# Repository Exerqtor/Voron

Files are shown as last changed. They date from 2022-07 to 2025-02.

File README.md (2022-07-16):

# Voron stuff

This is where i will upload my Voron related stuff, enjoy!

Check out the [`Mods`](./Mods) [`Firmware`](./Firmware) and [`SlicerConfigs`](./SlicerConfigs) folders for my mods that are still 
considered (by me) to be relevant. All abandoned mods can be found in the [`AbandonedMods`](./AbandonedMods) folder.

Voron Logo

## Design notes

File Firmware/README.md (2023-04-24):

# Firmware

My firmware configurations and Macros for Voron 3D printers, separated by firmware type.

## Table structure

Update the following table with the information about your mod:
- Your name
- A link to your sub-folder
- A short description of your firmware config
- The printer compatibility. Use `:heavy_check_mark:` for :heavy_check_mark:,`:x:` for :x: and `:grey_question:` for :grey_question:

like so:
`
| Creator | [Config Title](link) | Description | :x: | :x: | :x: | :x: |`

---
## RepRapFirmware

| Creator | Config title | Description | V0 | V1.8 | V2.4 | VSW | VT |
| --- | --- | --- | --- | --- | --- | --- | --- |
| Exerqtor | [Duet 3 Config](./reprapfirmware/) | My RRF 3.5 config | :x: | :x: | :x: | :x: | :heavy_check_mark:
|| [RRF Macros](./rrf-macros/) | RepRapFirmware macros for Voron printers| - | - | - | - | - | |

---

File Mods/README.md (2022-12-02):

# Mods

Printer mods for Voron 3D printers
Remember to update this README when uploading new mod!

## Legacy printers

Mods for legacy printers can be found [here](../legacy_printers/printer_mods).
If one of your mods applies to a current generation Voron printer, contact the admins in
Discord to have your mod moved to this folder.

## Table structure

Update the following table with the information about your mod:
- Your name
- A link to your sub-folder
- A short description of your mod
- The printer compatibility. Use `:heavy_check_mark:` for :heavy_check_mark:,`:x:` for :x: and `:grey_question:` for :grey_question:

like so:
`
| Creator | [Mod title](link) | Description | :x: | :x: | :x: | :x: | :x: |`

---

| Creator | Mod title | Description | V0 | V1.8 | V2.4 | VSW | VT |
| --- | --- | --- | --- | --- | --- | --- | --- |
|Exerqtor|[Revo nozzle storage skirt](./revo_nozzle_storage_skirt)| Revo nozzle storage that can hold 7 nozzles, for the side skirt(s). |:x:|:x:|:x:|:x:|:heavy_check_mark:|
||[StealthBurner / CW2 style LGX Lite mount](./stealthburner_cw2_style_lgx_lite_mount)| A lightweight Bondtech LGX lite mount for StealthBurner / CW2 carriage with detection filament sensor .|:x:|:grey_question:|:heavy_check_mark:|:grey_question:|:heavy_check_mark:|
||[Pepe pack v2](./pepe_pack_v2)| A rear mounted alternative to the Nevermore filter .|:x:|:grey_question:|:heavy_check_mark:|:x:|:heavy_check_mark:|
||[Quick release exhaust mount](./quick_release_exhaust_mount)| Quick release system ("Annex-style") for the exhaust housing on the rear panel.|:x:|:heavy_check_mark:|:heavy_check_mark:|:grey_question:|:heavy_check_mark:|
||[Trident PTFE Support-v2](./trident_ptfe_support-v2)| PTFE support arm that mounts on the top rear extrusion on a Trident, WITH bearing.|:x:|:x:|:x:|:x:|:heavy_check_mark:|
||[MGN12H rear Z carrier for Trident](./mgn12h_rear_z)| Rear Z carrier that allowes for the use of a MGN12H rail instead of MGN9H.|:x:|:x:|:x:|:x:|:heavy_check_mark:|
||[Trident PTFE Guides](./trident_ptfe_guides)| A guide for the PTFE tube into the extruder .|:x:|:grey_question:|:x:|:x:|:heavy_check_mark:|
||[VT Lowered Z Motor Mounts](./vt_lowered_Z_motor_mounts)| Z motor mounts that makes you use T8 leadscrews and couplers on a Trident.|:x:|:grey_question:|:x:|:x:|:heavy_check_mark:|
||[fume pack](./fume_pack)| A rear mounted alternative to the Nevermore filter, the successor of pepe pack v2 .|:x:|:grey_question:|:heavy_check_mark:|:x:|:heavy_check_mark:|

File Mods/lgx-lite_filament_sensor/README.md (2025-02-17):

# Filament runout sensor for Bondtech LGX lite (v1 & v2)

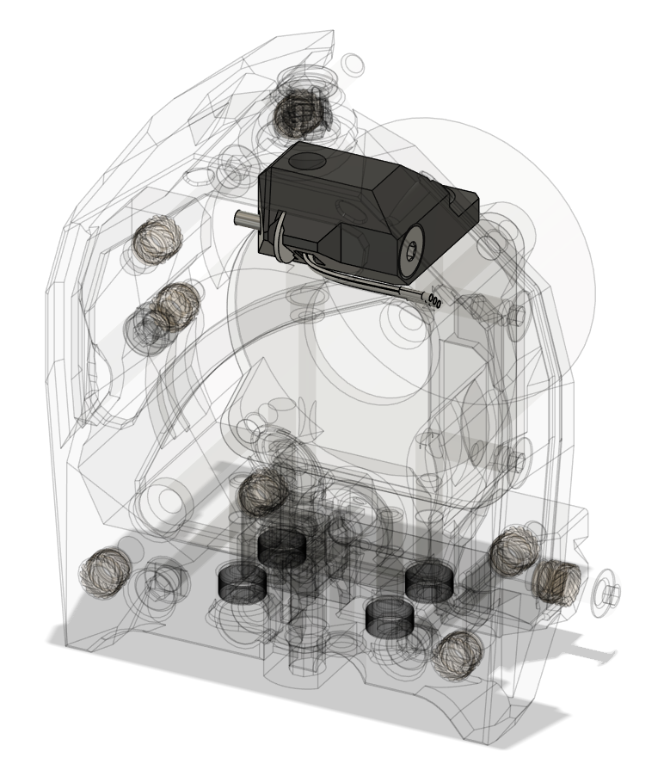
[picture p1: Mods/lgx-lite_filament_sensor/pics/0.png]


## CHANGELOG
- 17.02.2025: Initial release.

###### Printing:
- Default voron settings, correct orientation, no supports needed!

###### Bom:
- 2x 6mm FHCS - Needs to be stainless to avoid interference with the HALL sensor.
- 1x 3mm DIN washer - Needs to be steel to interact properly with the HALL sensor.
- 1x AH3364Q-P-B hall sensor - "Name brand" one from a reputable vendor  is adviced (but not a must).
- 1x 6x3mm magnet - Both N35 & N52 does the job, but N52 works the best.

###### Description:
- Initial design by Olof at Bondtech, and we've been collaborating to get it to it's current form. 
I've been testing different iderations of this for well over a year at this point and it's been working like a champ.
- The Sensor is meant to mount above the LGX Lite, inside Bondtechs mount (my MMU & Filametrix mounts are based of Bondtecs mounts so it naturally fits there too).

### !!ATTENTION!! This sensor does NOT work with the LGX Lite PRO, I have one in the works. But since i haven't got a LGX Lite PRO to test with this isn't getting prioritized. 

###### Assembly instructions:
- Prep the printed part by making sure any strings, blobs etc. is removed.
- Get the FHCS screw started about 2mm. into the side of the sensor body.
- Insert AH3364Q-P-B in it's slot.
  - If needed use a exacto knife to remove any print debris from the hall sensor slot so that it seats fully.
- Tighten down the screw while making sure the AH3364Q-P-B is still seated properly in the sensor housing.
- Insert the magnet and then the washer in their locations.
  - If the magnet feels a little loose when you put it in it's best to add a tiny drop of CA-glue or nail polish to secure it.
- Snip off a stump of 1.75mm filament and insert it into the hole in the side of the sensor body to retain the washer (and trim it to size, but leave enough that you can still use some pliers to remove it).
- Do a bench test with some filament and check that it can pass through the sensor without any issues.
- If you haven't done so allready you should now solder on some wires to the hall sensor before you bend the pins flush to the sensor body (like shown in the renders).
- Cut a piece of PTFE with the jig and insert it to the top/filament entrence of your LGX-lite.
- Mount the filament sensor with a the remaining 6mm FHCS (both 6mm and 8mm should work fine for this).

- I'm not gonna go into how you're supposed to solder, wire up & configure the HALL sensor for your machine but there’s more than enough information on the internet for you to figgure that out yourself ;)  

###### Pictures:
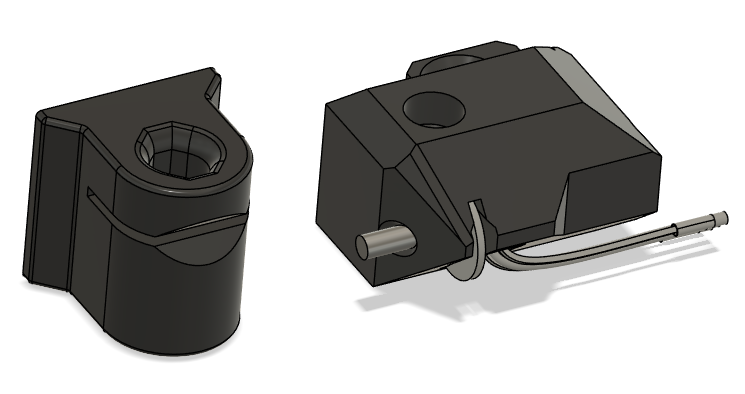
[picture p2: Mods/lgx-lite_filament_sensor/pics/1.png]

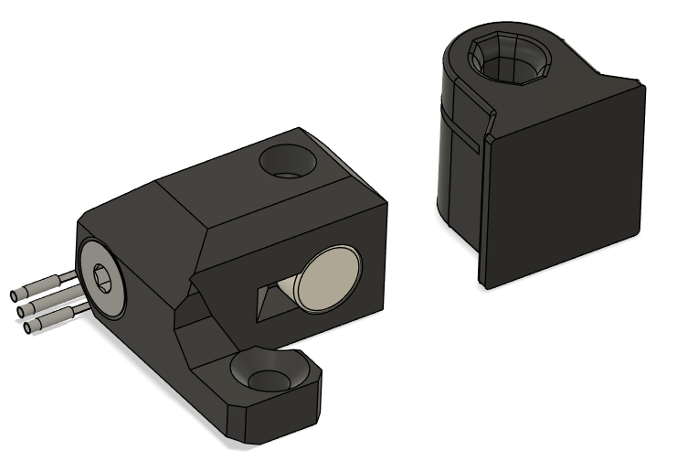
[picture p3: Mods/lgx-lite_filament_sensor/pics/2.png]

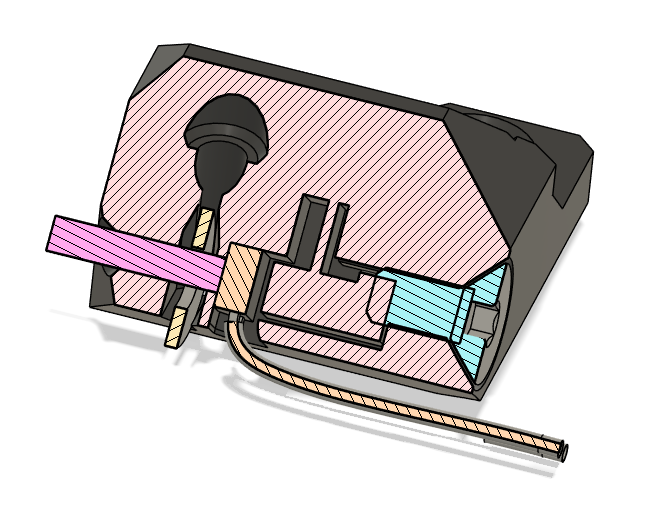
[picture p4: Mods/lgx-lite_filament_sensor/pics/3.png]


###### To-do List
- Nothing that i can think of.

##### Credits:
- Olof Ogland
- [ERCF project](https://github.com/Enraged-Rabbit-Community/ERCF_v2) for much of the sensor geometry.

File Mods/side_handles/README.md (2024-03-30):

# 2.4 & Trident side handles
### **CHANGELOG:**
- 30.03.2024: Initial release.

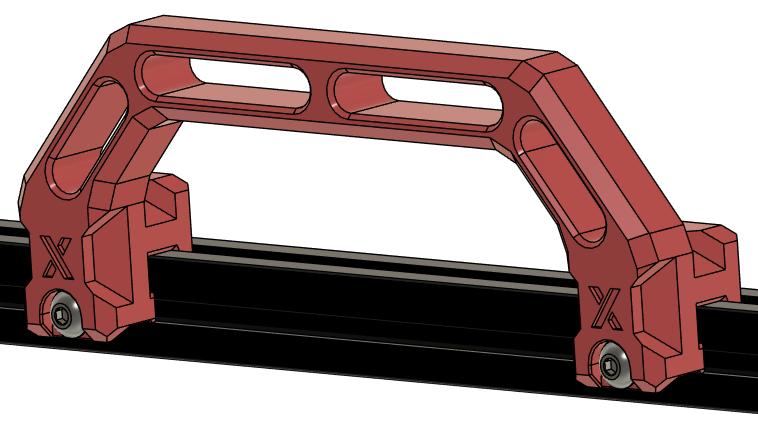
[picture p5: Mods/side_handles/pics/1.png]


### **Description:**
- I've been using the original “Sturdy Handles” before and they've done their job, but then I saw ["JSB's X-Handle"](https://www.printables.com/model/350891-voron-24-x-handle)  and I liked them, but they had some issues with the design. So I ended up doing the following:

- Removed the top mounting bolts in favour of a “lip” that goes into the 2020 extrusion like the original “sturdy handles”
- Added M3x20mm BHCS to mitigate a weak spot in the design where the handle meets the top part, where it "allways" cracked.
- Made modifier blocks to add denser/stronger types of infill around the problem area mentioned above.
- I've also made a second modifier block that makes it possible to add "fuzzy skin" to the handle without compromising the structual integrety while still giving that nice grippy texture (for those who wants it).

*I've also made a version of the handle that's stripped of the “X” since I just don't understand why it's there at all other than nonsensical “branding” (?) , to each their own i guess!*

### **Pictures:**
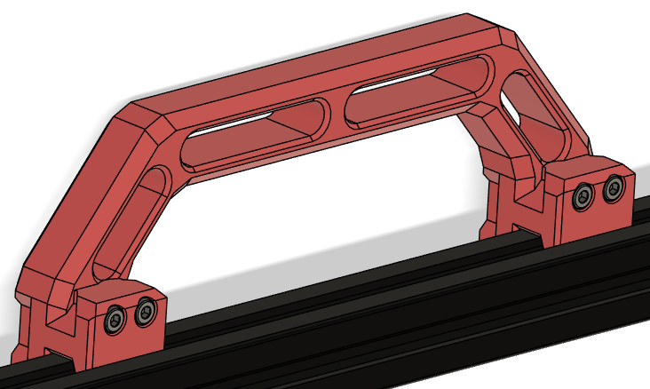
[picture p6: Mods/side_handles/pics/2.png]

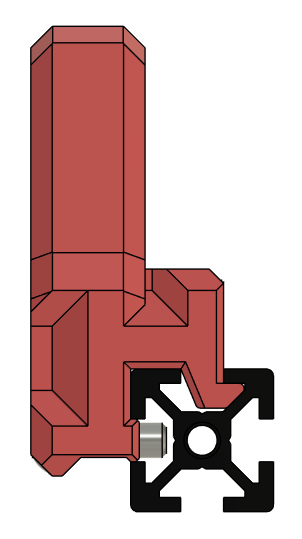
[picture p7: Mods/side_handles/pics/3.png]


### **Printing:**
- Default voron settings, correct orientation, no supprts needed!
- First load the handle itself to your slicer.
- Add "Infill.stl" as a modifier to the handle and adjust the infill properties of the modifier.(if you want to add other infill properties to the stress sones).
- Add "Fuzz.stl" as a modifier to the handle and enable fuzzy skin (contour) to the modifier (if you want to add texture to the handle).
If you've gone with both infill and fuzz you will end up with something like this:

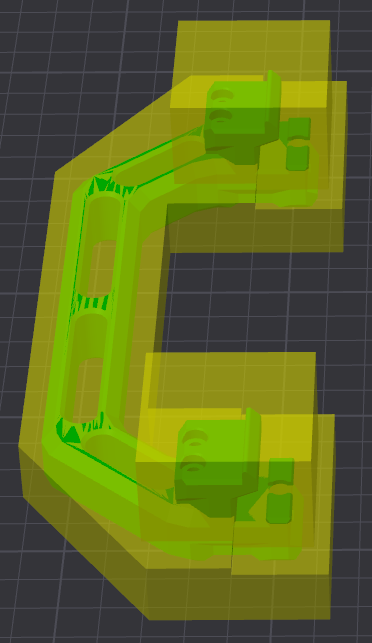
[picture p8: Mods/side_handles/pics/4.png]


This is the sliced view of mine when I use 40% Support Cubic infill on the handle, 40% 3D Honeycomb on the infill modifier & Countor fuzzy skin on the fuzz modifier:

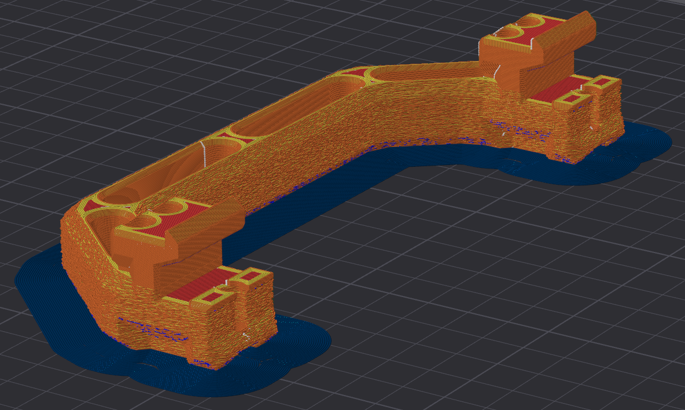
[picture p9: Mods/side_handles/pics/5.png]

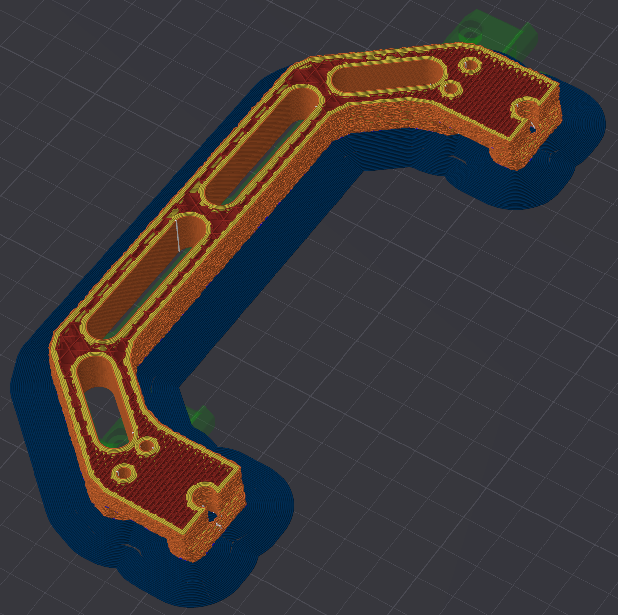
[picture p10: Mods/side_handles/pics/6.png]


### **BOM (per side):**
- 4x M3x20mm SHCS (for the handle reinforcement)
- 2x M5x16mm  BHCS
- 2x M5 Roll-in T-nuts

###### **To-do List:**
- Nothing that i can think of.

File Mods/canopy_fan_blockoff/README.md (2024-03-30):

# Canopy fan blockoff plates
### CHANGELOG
- 30.03.2024: Initial release.

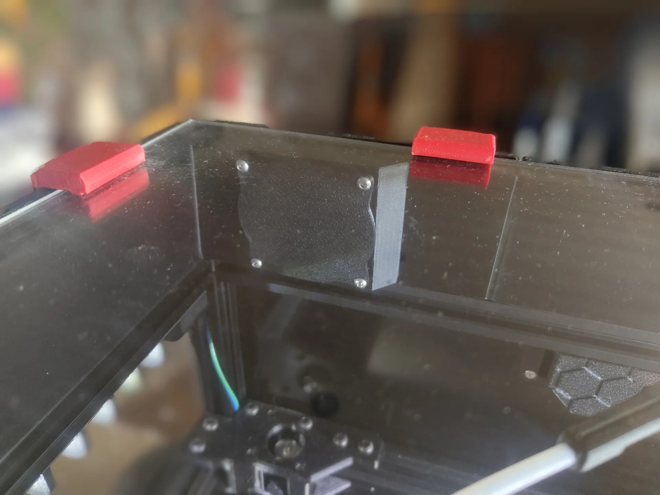
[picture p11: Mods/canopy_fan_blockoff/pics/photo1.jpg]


### Description:
- I didn't want to re-print the rear corners of  ["JSmith17's Canopy"](https://www.printables.com/model/568090-voron-24-canopy) in case I eventually add exhaust fans, so i made these blockoff plates instead.

### Pictures:
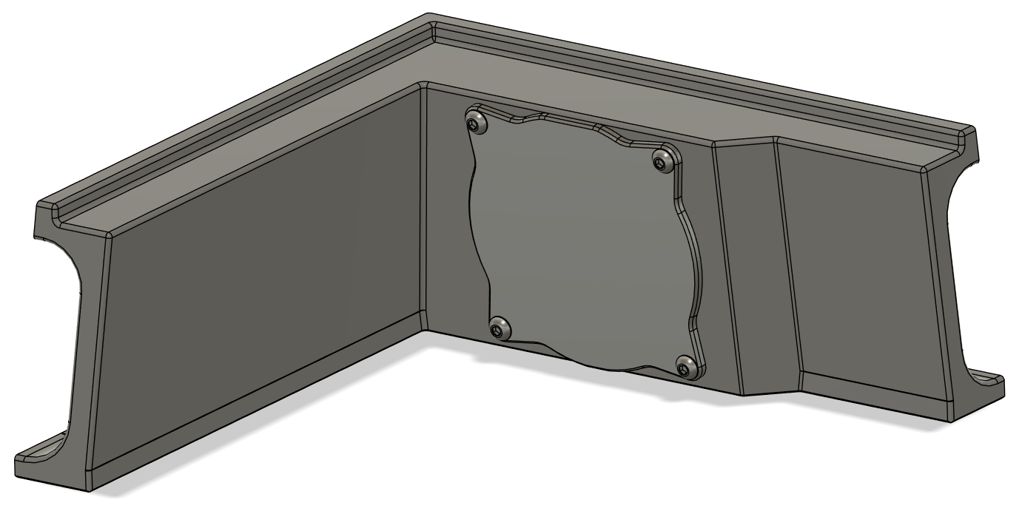
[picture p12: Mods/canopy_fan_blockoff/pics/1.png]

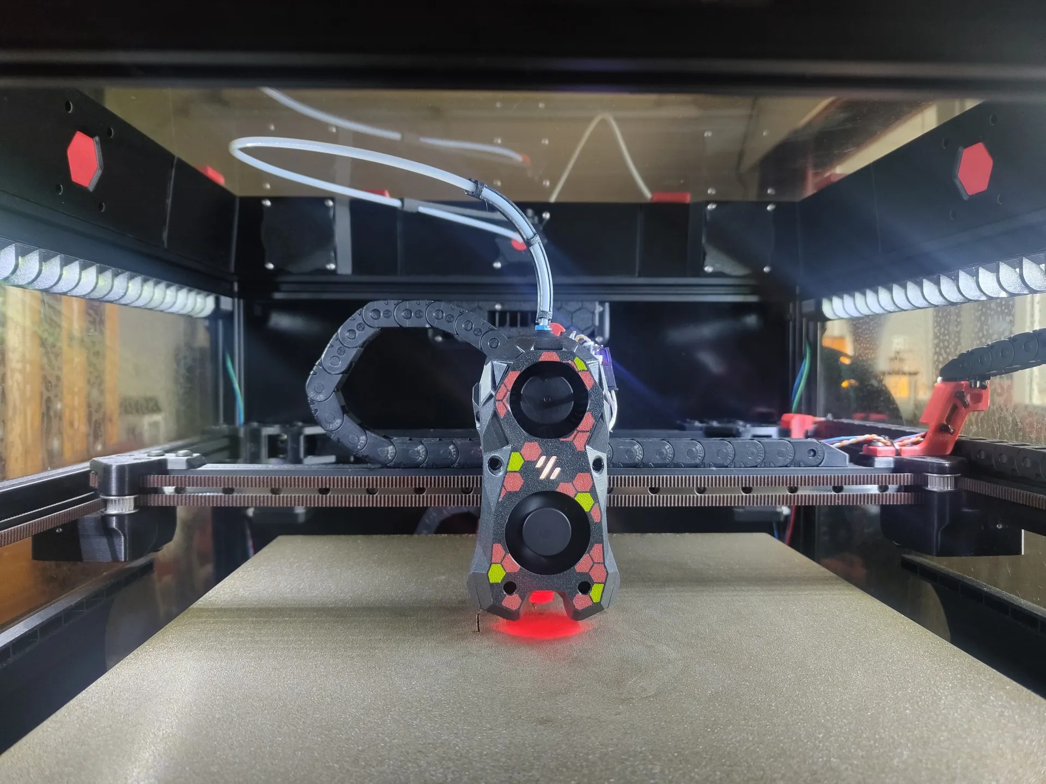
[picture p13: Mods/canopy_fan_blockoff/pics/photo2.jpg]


### Printing:
- Default voron settings, correct orientation, no supports needed.

### BOM
- 4x M3x6mm BHCS
- 4x M3x5x4mm Heat sets

### To-do List
- Nothing that i can think of.

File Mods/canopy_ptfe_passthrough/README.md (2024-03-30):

# Canopy PTFE passthrough
### CHANGELOG
- 30.03.2024: Initial release.

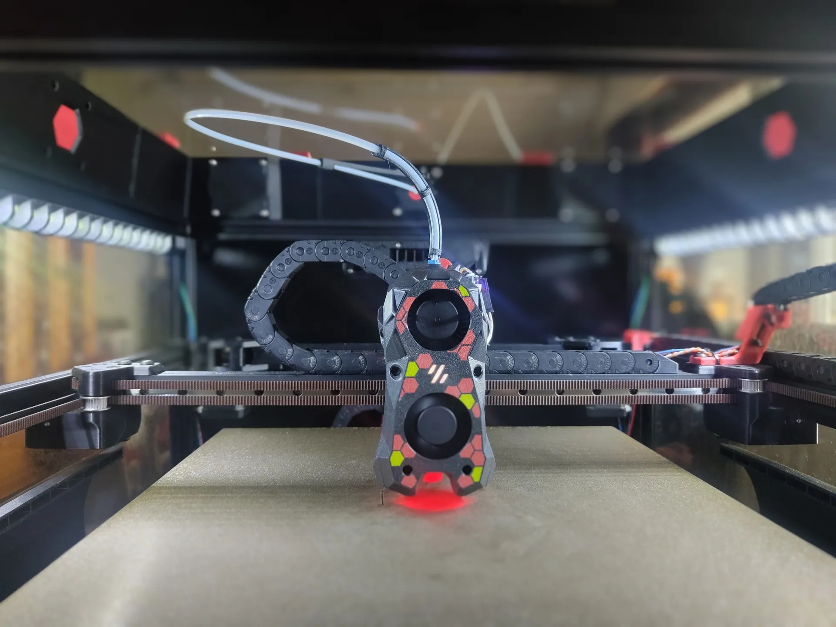
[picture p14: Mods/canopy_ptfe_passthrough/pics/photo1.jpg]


### Description:
- I'm running both a Nevermore Stealthmax (which have sub-ideal PTFE routing) and ["JSmith17's Canopy"](https://www.printables.com/model/568090-voron-24-canopy) on my Trident so I thought I'd make a better and more elegant way to route the PTFE-tube.
And this is what it ended up with making, it removes the logo from the rear (or where ever you want your PTFE tube to enter) middle Canopy section and adds a “UM2-style” PTFE connector to it. 
- I've also made a mount for my PTFE-tube support to help guide the tube around (designed with Trident in mind, but works just as good on a 2.4). For a Trident you also need to use the Trident PTFE Guides to help steer the tube neatly (for me the “R50-90°”  works best).

### Pictures:
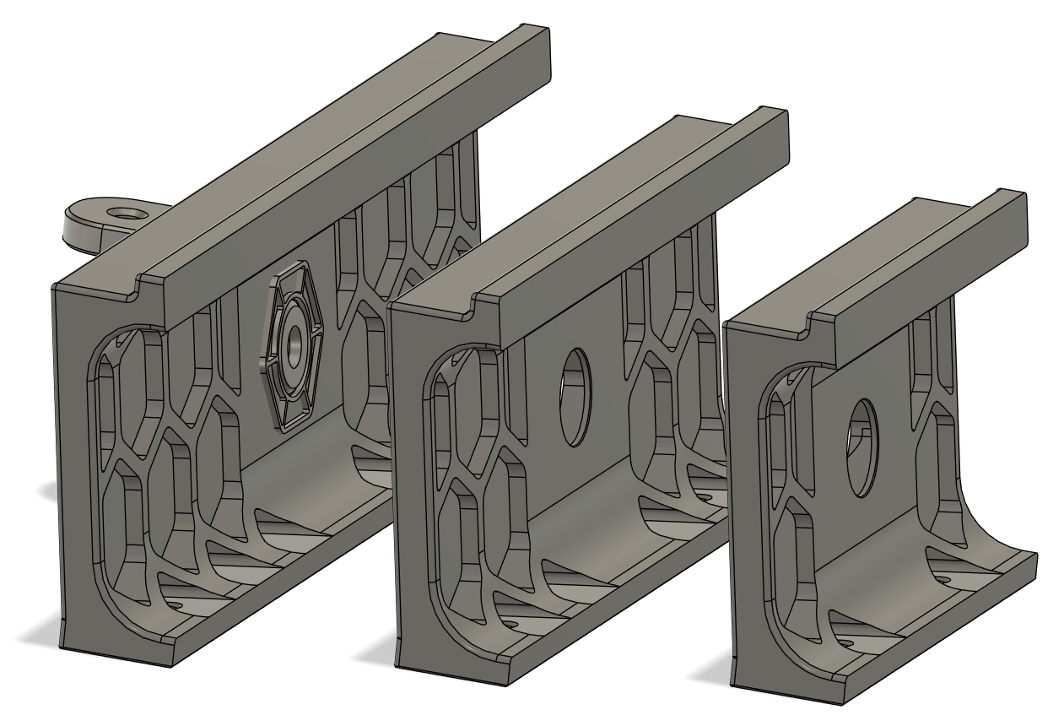
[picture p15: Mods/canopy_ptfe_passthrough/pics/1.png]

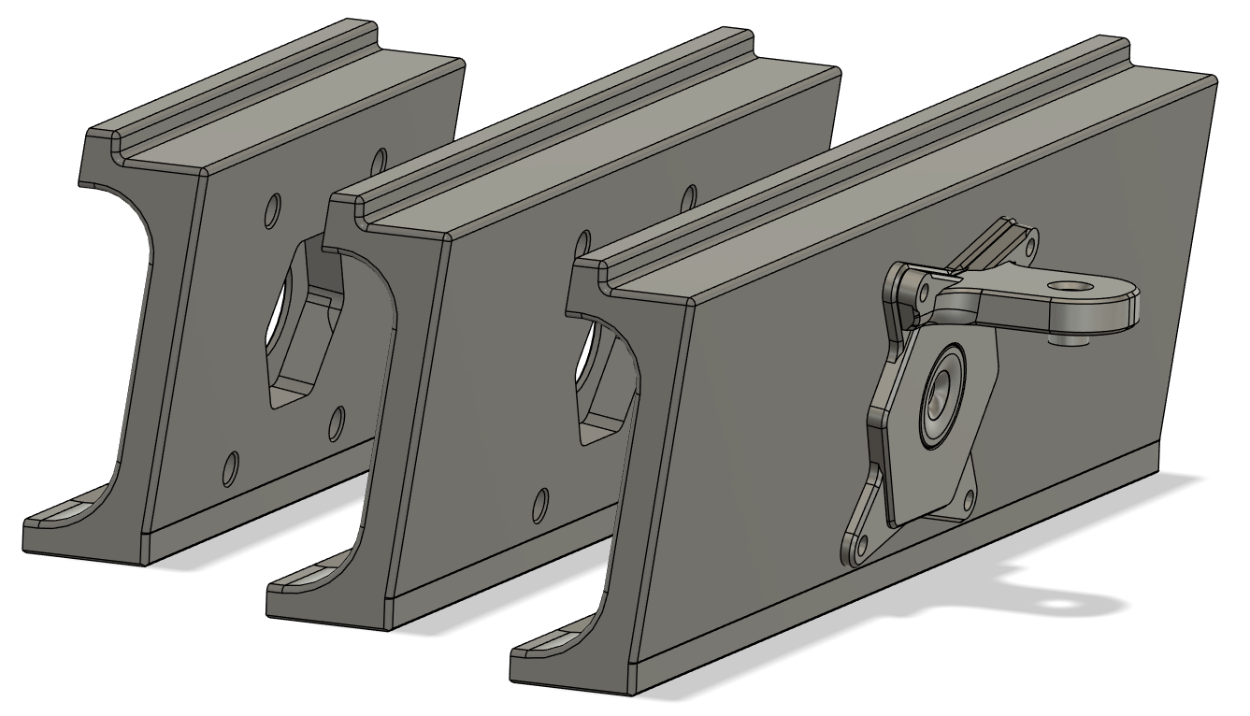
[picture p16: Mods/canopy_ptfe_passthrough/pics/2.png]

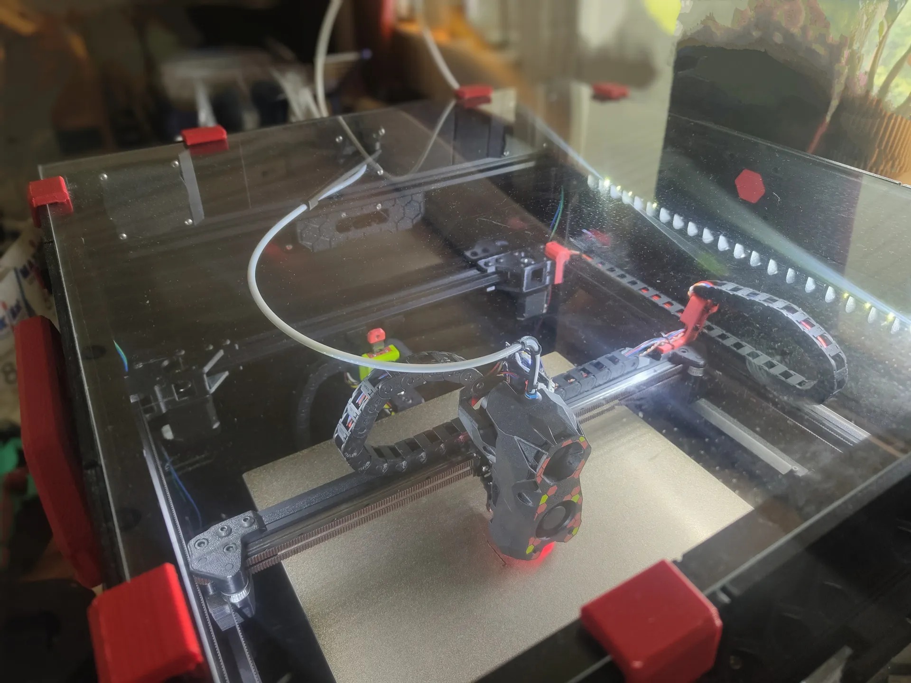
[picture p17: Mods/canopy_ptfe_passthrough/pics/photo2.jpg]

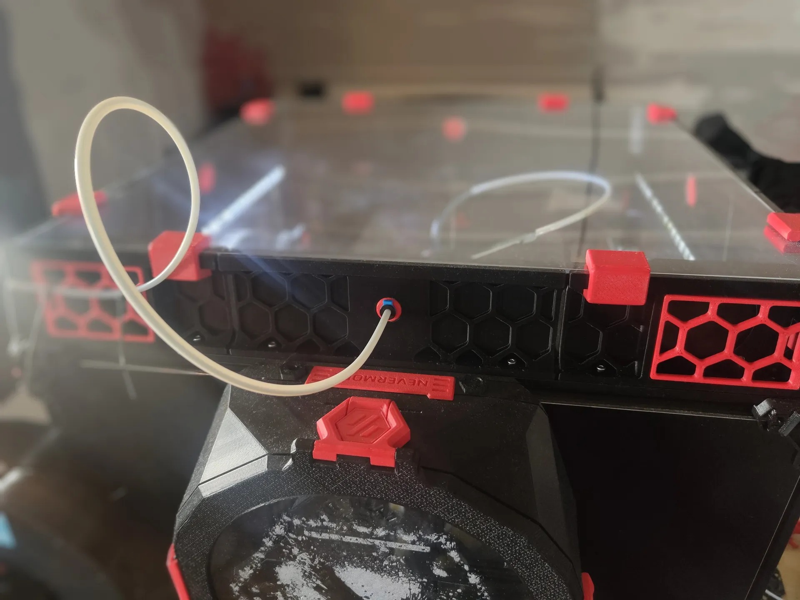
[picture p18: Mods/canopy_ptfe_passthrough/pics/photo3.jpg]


### Printing:
- Default voron settings, correct orientation.
- Supports needed on the Canopy part, refere to the "Canopy sides" description from my ["Canopy side handles mod"](https://github.com/Exerqtor/Voron/tree/main/Mods/350mm_canopy_side_handles).

### BOM

**Without guide:**

- 4x M3x6mm BHCS
- 4x M3x5x4mm Heat sets
- 1x "UM2-style" PTFE connector

**With PTFE guide:**

- 2x M3x6mm BHCS
- 2x M3x8mm BHCS
- 4x M3x5x4mm Heat sets
- 1x M5x10mm BHCS
- 1x MR85 bearing
- 1x "UM2-style" PTFE connector

### To-do List
- Nothing that i can think of.

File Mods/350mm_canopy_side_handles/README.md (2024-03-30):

# 2.4 & Trident  350mmCanopy side handles
### **CHANGELOG:**
- 30.03.2024: Initial release.

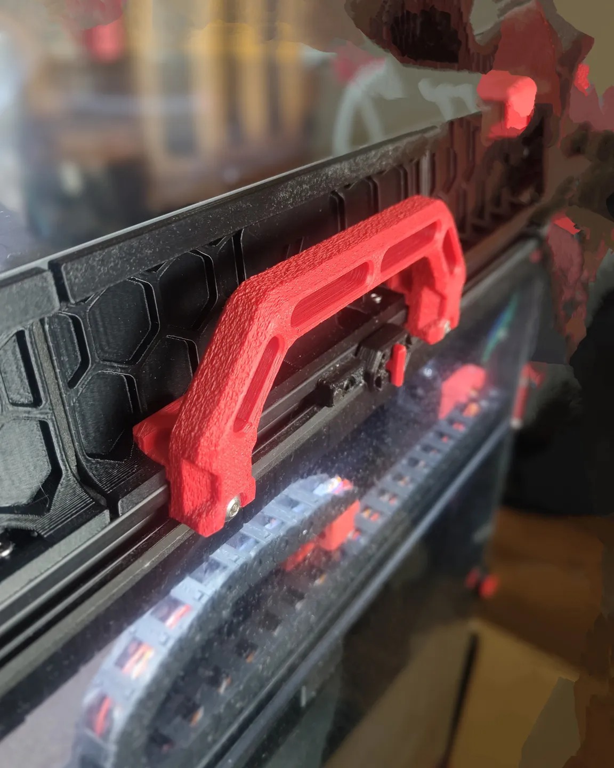
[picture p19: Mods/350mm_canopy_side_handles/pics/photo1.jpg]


### **Description:**
- I didn't want to remove the handles on my Trident when I started to print ,["JSmith17's Canopy"](https://www.printables.com/model/568090-voron-24-canopy) but didn't like the avalible options.
- I've been using the original “Sturdy Handles” before and they've done their job, so i saw ["JSB's X-Handle"](https://www.printables.com/model/350891-voron-24-x-handle)  and started working on a way to add compatibility for those on the Canopy.

**Canopy:**
- Moved the mounting holes inward one “octagon”.
- Made the needed cutouts for the handles to sit within.

**X-Handle:**
- Removed the top mounting bolts in favour of a “lip” that goes into the 2020 extrusion like the original “sturdy handles”
- Added M3x20mm BHCS to mitigate a weak spot in the design where the handle meets the top part, where it "allways" cracked.
- Made modifier blocks to add denser/stronger types of infill around the problem area mentioned above.
- I've also made a second modifier block that makes it possible to add "fuzzy skin" to the handle without compromising the structual integrety while still giving that nice grippy texture (for those who wants it).

*I've also made a version of the handle that's stripped of the “X” since I just don't understand why it's there at all other than nonsensical “branding” (?) , to each their own i guess!*

### **Pictures:**
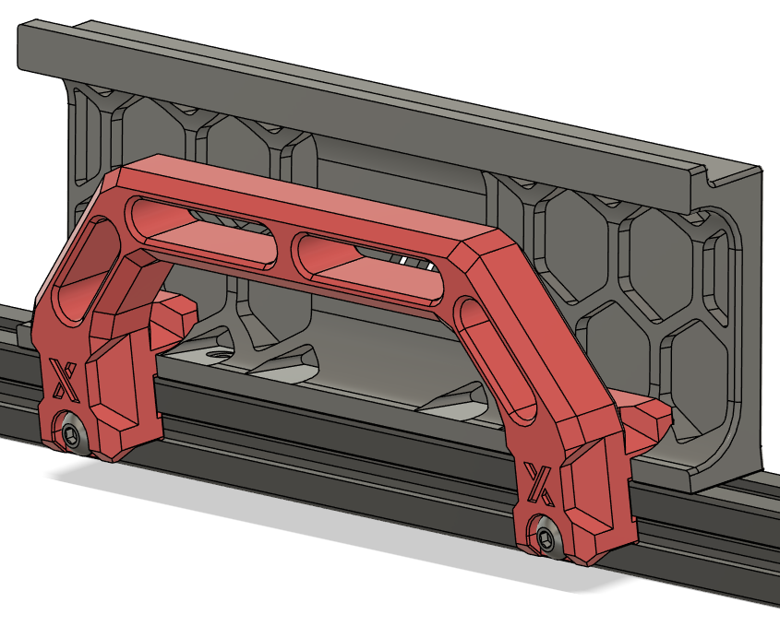
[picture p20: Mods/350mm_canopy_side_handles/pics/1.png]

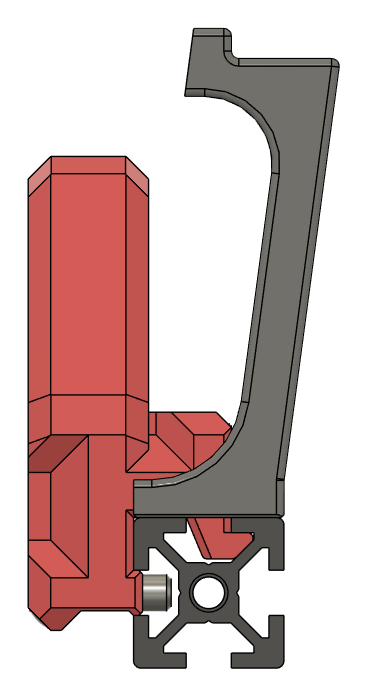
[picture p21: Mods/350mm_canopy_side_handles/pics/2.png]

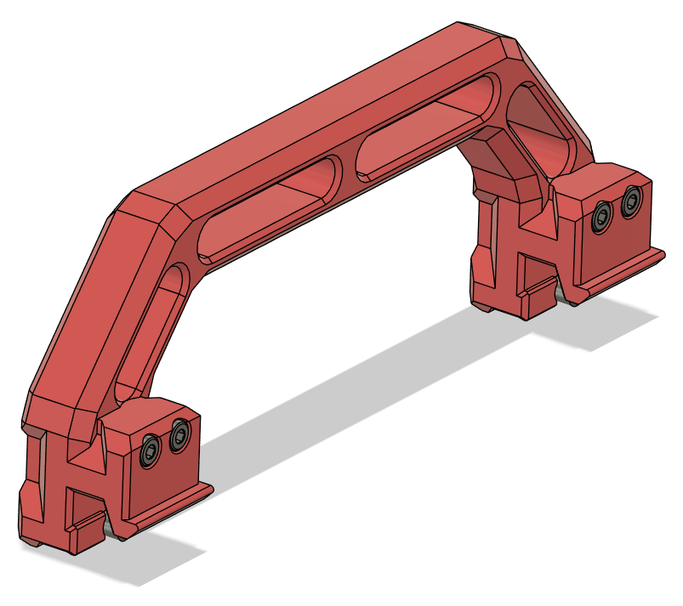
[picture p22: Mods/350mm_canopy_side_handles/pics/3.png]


### **Printing:**
**Canopy sides:**
- Default voron settings, correct orientation.
- You **MUST** add supports, I went for organic/three supports like this: 

Front side

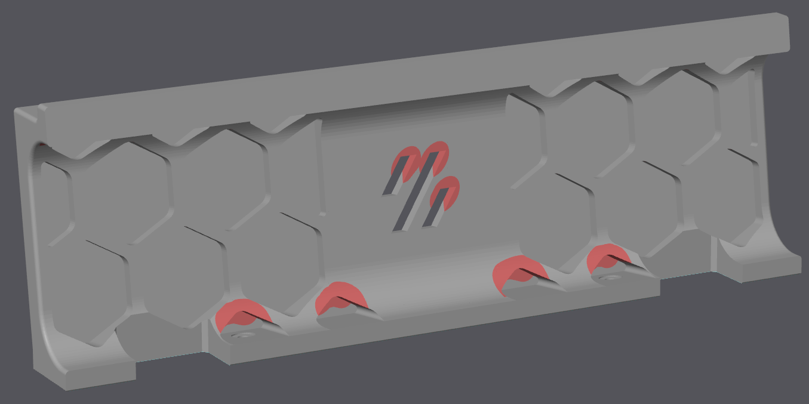
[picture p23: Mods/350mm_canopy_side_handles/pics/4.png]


Back side

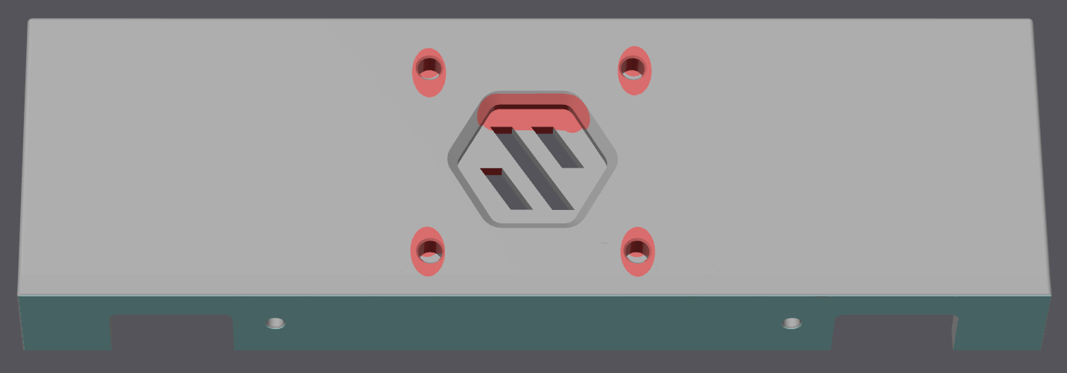
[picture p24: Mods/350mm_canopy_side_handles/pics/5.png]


Result:



**Handles:**
- Default voron settings, correct orientation, no supprts needed!
- First load the handle itself to your slicer.
- Add "Infill.stl" as a modifier to the handle and adjust the infill properties of the modifier.(if you want to add other infill properties to the stress sones).
- Add "Fuzz.stl" as a modifier to the handle and enable fuzzy skin (contour) to the modifier (if you want to add texture to the handle).
If you've gone with both infill and fuzz you will end up with something like this:



This is the sliced view of mine when I use 40% Support Cubic infill on the handle, 40% 3D Honeycomb on the infill modifier & Countor fuzzy skin on the fuzz modifier:




### **BOM (per side):**
**Canopy sides:**
- 2x M3x8 SHCS (I choose to use low profile ones)
- 2x M3 Roll-in T-nuts

**Handles:**
- 4x M3x20mm SHCS (for the handle reinforcement)
- 2x M5x16mm  BHCS
- 2x M5 Roll-in T-nuts

###### **To-do List:**
- Nothing that i can think of.

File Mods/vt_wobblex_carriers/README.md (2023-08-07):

# Trident WobbleX carriers
## CHANGELOG
- 08.07.2023: Merged all my Wobblex mods into this one repo to make it easier (it was split into one repo for front, one for rear + one for rear-MGN12H before). This also brings the release of the leadscrew top supprts!
- 06.08.2023: Changed the Wobblex logo from an Emboss to a Deboss to better fit with the "Voron ethos", since all offical Voron logos are debossed rather than embossed.
- 01.05.2023: Opened up the center hole (where the leadscrew goes through) too 13mm to allow for more leadscrew movement without interfering witht he carrier body.
- 25.04.2023: Variable pin sizes for WobbleX carriers, since it's been some issues with the pin sizes being either too small or large I've made a little test model so you can determine what suits you best. When you've found the right size for you then you choose the corresponding set of carriers & TR8 adapters.
- 23.04.2023: Initial release.
- 15.04.2023: WobbleX v1.7, resized the pin holes too 2.9mm (the old/stock was 3.1mm and the pins would be loose and fall out).
- 15.04.2023: WobbleX v1.6, added recess for the WobbleX balls (missing in stock/MGN9H release too).
- 11.04.2023: WobbleX v1.5.
- 11.04.2023: WobbleX v1.

###### Printing:
- Default voron settings, correct orientation, no supports needed!

###### Bom:
- 3x WobbleX WS8 
- Stock Voron Trident screws etc.

###### Description:
- Since it's been a couple issues with the stock rear [WobbleX](https://github.com/MirageC79/Interfaces-for-WobbleX-integration/tree/main/Voron/Trident) Z carrier, which i have fixed for my MGN12H version i figured i could apply the same fixes to the MGN9H so that it's out there for those who need it. So here you go, enjoy!
- It's also been some issues with the pin sizes being either too small or large I've made a little test model so you can determine what suits you best. When you've found the right size for you then you choose the corresponding set of carriers & TR8 adapters.
- I've also made a set of Solid front carriers to use with your brand new Wobblex setup (if you don't mind printing more than "just" the adapter plate).
- Lastly I've also made a set of top supports for the leadscrews since they tend to flop around everywhere if they are bent (and i suspects thats the reason why you went with Wobblex in the first place. These use some tiny (and cheap) MR85 bearings you can get from the usual suspects.
if you have leadscrews that's got a 5mm "nubbin" at the top you should be able to use these supports without the bearing-leadscrew adapers since the MR85 bearings are have a 5mm ID.

You will loose a tiny bit of Z travel, otherwise it's not much to "negative" (quite substantial loss of Z travel with WobbleX, but that's not isolated to this mod, it's just the nature of the beast). 

For those who choose to run MGN12H in the rear i've also added a a modifed rail stop to fit the MGN12 rail!

###### Pictures:







10.5mm(old) vs 13mm(new)




The pin test block



The top supports



###### To-do List
- Nothing that i can think of.

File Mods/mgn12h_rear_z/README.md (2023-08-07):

# MGN12H rear Z carrier for Trident
## CHANGELOG
- 07.08.2023: Moved the Wobblex carrier over to it's own mod.
- 30.11.2022: Initial release.

###### Printing:
- Default voron settings, correct orientation, no supports needed!

###### Bom:
For "standard" carriers:
- Same as stock Trident except a MGN12H rail set.

###### Description:
- Modifed Voron Triden r1 rear Z carrier to house a MGN12H block instead of MGN9H.
- One version for IGUS chains (2bolt), and one version for the generic Chinese ones (3bolt).
- Rail stop that's been sized to accommodate for a MGN12 rail.

###### Pictures:


###### To-do List
- Nothing that i can think of.

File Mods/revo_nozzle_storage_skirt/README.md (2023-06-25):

# CHANGELOG
- 25.06.2023:  A&B "sides" tolerance tweaking and new "Revo logo" plus renaming. I never realy liked the font and look of the "REVO" text on the lid, so i've now changed font to the same E3D use in much of their revo marketing. I also changed the text to  "Revo™". 
I've also made a A & B side now. So now we can stock up 28 nozzels on our Tridents if we so wish! Almost forgot to mention it, but i've also redone the nozzle carrier so it's less clunky AND easier to open. AND for those who want to print the MM/mesh version, I've added brim ears as a separate part since i've experienced issues with the tips warping during filamentchanges.
- 20.04.2023: Did a brainfart when i exported the MM lid, and didn't select all the parts to export as one .stl. now that's fixed.
- 18.04.2023: v2, This is the first of a "rewamp" of this mod, cleaned up the cad, added the option for meshed backing, adjusted some clearances. More to come!
- 16.07.2022: Initial release, this is NOT the finished or polished "product" but it works! I will update the design and publish the CAD (with updated STL's ofc) as soon as i can!
This is ONLY for the left side on a 350mm Trident!

## Revo nozzle storage skirt
##### Credits:
- Voron Discord channel user Andre#7463 (So I says...), he was the one who made the initial design and supplied the CAD that i worked of for the skirt part.
- Printables.com user Fabian, for his awesome take on retaintng the nozzles on the ["E3D Revo Nozzle Organizer (Bosch Pick & Click)"](https://www.printables.com/model/102698-e3d-revo-nozzle-organizer-bosch-pick-click) 

###### Printing:
- Default voron settings, correct orientation, no supports needed!

###### Bom:
- 2x M3x8 SHCS
- 2x 6x3mm Magnets

###### Description:
- I've been planning to make a solution to store the Revo nozzles on my VT since i joined the pre-order, but hav been putting it off until "So I says..." posted his mod in discord.
When I saw it I finally got the creative juices flowing and jumped right on it. I had allready come across a nice design on Printables for the nozzle retention part that I had planned on
using allready, so I got to work putting this together into something usefull. And well, this is how it ended up. The 350mm variant can store 7 Revo nozzles (only 350mm avalible at the time of writing this).

###### Pictures:





###### To-do List
- Add a "stopper" for the nozzle holder so that it stops in the middle of the opening.
- Add left & rear versions for 350mm.
- Add support for 300mm & 250mm printers.

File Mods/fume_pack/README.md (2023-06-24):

# fume pack

## CHANGELOG
- 24.06.2023: DXF changes, the mounting holes have been changed to 4mm. And files for Voron 2.4, this meant changing all the DXF file names to "VT" & "V2" respectively.
- 20.06.2023: DXF Files. I've exported & upload DXF files to cut the rear panels, these will “only” include the fan holes and the bolt pattern for the 5-bolt version. The wiring holes and/or extra bolt holes for 13-bolt version must be drilled by hand. This includes all standard sizes pluss a “custom” 350x350mm variant (350mm with 350mm Z-axis).
- 04.12.2022: [Version 1.2.1 "Main bodies" ](https://github.com/Exerqtor/Voron/tree/main/Mods/fume_pack/changelog/v1.2.1): I had to add little feature on the outside of the main bodies to compensate for the lost wall thickness introduced due to the detachable backplate in v1.2.
- 03.12.2022: [Version 1.2 "Main bodies"](https://github.com/Exerqtor/Voron/tree/main/Mods/fume_pack/changelog/v1.2): to have some more flexibility in regards of different cartridges I've made the "plate" on the main body bellow the exhaust vent a separate piece.
Future releases might call for the plate to be swaped out infavor of a new design, but that's way better than having to reprint the whole main housing.
All v1.2 Main bodies and cover plate go together with v1.1 cartride just to be clear.
It's got built in supports for the overhanging parts in the main body so it shouldn't be any problem printing this, if you run into some issues, please let me know ASAP!   
- 02.12.2022: Moved the wire routing holes that exit right bellow the rear gantry extrusion (VT) down a little bit, this efects all "main bodies" & the drill template.
- 01.12.2022: Initial release, refere to description..

###### Description:
Since the "fume pack" is directly dervied from ["Pepe pack v2.2"](https://github.com/Exerqtor/Voron/tree/main/Mods/pepe_pack_v2) I will only mention the changes done from that point and forward:
- Ground-up rework of the carbon container/cartridge/basket (what ever you eant to call it) to closer resemble the Nevermore Micro V5 Duo.  In other words should "fume pack" do the job exactly like a stock V5 Duo, if not better since the basket has a somewhat larger surface area of carbon for the air to pass thru.
- With the new cartridge the carbon abmount is roughly cut in two compared to "pepe pack" and now pretty much the same as aevermore Micro V5 Duo.
- Redesign of the fan lid, with deeper holes in the main body to accept 8mm bolts.

# It shouldn't need to be mentioned, BUT before someone tears me a new one for "being at fault for them fucking up their back panel with to many holes": MAKE SURE YOU DRILL ONLY THE HOLES NEEDED FOR YOUR PARTICULAR APPLICATION!!

- If you choose to use the fan gaskets or not is totally up to you, i don't think they have THAT much of an effect but hey. Just for gods sake print them in a soft TPU, nothing "solid".
- Same goes for bolting down the fans, the fan lid is designed to firmly hold the fans in place. But how well that works depends on your fans!

I want to point out that the fans need to be cut up to work as intended(for those who didn't know). 
- [This is how the fans is supposed to look after cutting](https://raw.githubusercontent.com/Exerqtor/Voron/main/Mods/fume_pack/pics/fancut1.png). 

Regarding cutting the fans i will try to either make a little guide, or at least a cuting guide so you can mark of where to cut them correctly.

The fan holes in the rear panel should be 38mm, some wiggle room is allowed (within reason).

## And finally, choose the main body who suits your needs the best, both "5-bolt" and "13-bolt" version have three variants with PTFE holes either on all three sides, both sides OR rear only (like stock Voron) 

And as allways, if you have any ideas for new features or improvement give me a ding!

###### Pictures:










###### Bom:
13-Bolt:
- 11x M3x8mm BHCS (or SHCS)  - To mount the main body to the back panel (re-use the stock exhaust grill screws).
- 4x M3x8mm BHCS  - To mount the fans to the main body (optional).
- 13x M3x5x4mm Heat sets - To mount the main body to the back panel.
- 4x M3x5x4mm Heat sets - To mount the fans to the main body (optional).
- 8x 6x3mm Magnets (N35 works, but N52 is the best way to go) - to hold the basket on to the main body.

5-Bolt
- 3x M3x8mm BHCS (or SHCS)  - To mount the main body to the back panel (re-use the stock exhaust grill screws).
- 4x M3x8mm BHCS  - To mount the fans to the main body (optional).
- 5x M3x5x4mm Heat sets - To mount the main body to the back panel.
- 4x M3x5x4mm Heat sets - To mount the fans to the main body (optional).
- 8x 6x3mm Magnets (N35 works, but N52 is the best way to go) - to hold the basket on to the main body.

###### Printing:
- Default voron settings, correct orientation, no additional supports needed (other than the build in ones)!

###### To-do List
- Make a better readme / instructions.
- Different cartridges with HEPA filters, echaust feature etc. time will show.
- MAYBE a simple filament runnout sensor attachment.

##### Credits:
- [Pepe pack v2's](https://github.com/Exerqtor/Voron/tree/main/Mods/pepe_pack_v2) predecessor `smooshworx`'s mod called ["pepe-pack"](https://github.com/smooshworx/pepe-pack) and it's CAD. Pepe pack is based on `DoubleT`'s ["Funny Pack"](https://github.com/3DPrintingMods/Voron/tree/master/Mods/funny_pack). Fanny Pack is then again based on `oab1`'s ["FannyPack"](https://github.com/oab1/VoronMods/tree/main/v2.2%20Recirculating%20Filter)
- The ["Nevermore Micro V5 Duo,"](https://github.com/nevermore3d/Nevermore_Micro), who the fume pack is heavily moved back to when it comes to specifically the cartridge design.

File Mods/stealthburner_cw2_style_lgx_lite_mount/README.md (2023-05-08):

# Stealthburner CW2 style LGX Lite Mount
## CHANGELOG
- 08.05.2023: "Release version", updated design using the latest version of Eytecz mod (as of the time of writing this), Choose to rise the left side of the shell a little bit to flow better with the Stealthburner aestethics. This version still use the same chain mount as before btw, i will add another set of spacers for those who use tap later (or you can just "stretch" them by 2mm in your slicer).
- 07.08.2022: Initial release, this is based on the Stealthburner beta files, a new one will be made for the RC1 files (or newer, what ever's out when i get time).

## LGX Lite mount for CW2 X carrier and stealthburner
##### Credits:
- Eytecz here on gitub, this is a chopped down version of ["his mod"](https://github.com/Eytecz/LGX_Lite_Stealthburner_CW2_style_mount).

###### Printing:
- Default voron settings, correct orientation, no supports needed!

###### Bom:
- 4x M3x16mm SHCS - for screwing down the LGX Lite to the mount
- 1x AH3364Q-P-B hall effect switch - for the filament sensor
- 1x M3x8mm SHCS - to hold down the hall effect switch
- 1x 6x3mm Magnet - for the filament sensor
- 1x Standard M3 washer(must be magnetic) - for the filament sensor
- 1x M3x5x4mm Heat sets - for the rear body
- 1x M3x25,, SHCS - for bolting the two parts together

###### Description:
- I thought the mount Eytecz had made was too big and clunky, so i decided to shave it down and expose the LGX Lite without having the "cocoon".
- This also works with my Duet3D 1LC v1.2 mount!

###### Pictures:
Release version:;





RC1 Version:




Paired with my 1LC mount

How it looks with my 1LC mount

###### To-do List
- Check so that i'm 100% sure it works with Stealthburner RC1.

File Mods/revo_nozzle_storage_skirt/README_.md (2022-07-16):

# UPDATE
- 16.07.2022: Initial release, this is NOT the finished or polished "product" but it works! I will update the design and publish the CAD (with updated STL's ofc) as soon as i can!
This is ONLY for the left side on a 350mm Trident!

## Revo nozzle storage skirt
##### Credits:
- Voron Discord channel user Andre#7463 (So I says...), he was the one who made the initial design and supplied the CAD that i worked of for the skirt part.
- Printables.com user Fabian, for his awesome take on retaintng the nozzles on the ["E3D Revo Nozzle Organizer (Bosch Pick & Click)"](https://www.printables.com/model/102698-e3d-revo-nozzle-organizer-bosch-pick-click) 

###### Printing:
- Default voron settings, correct orientation, no supports needed!

###### Bom:
- 2x M3x8 SHCS
- 2x 6x3mm Magnets

###### Description:
- I've been planning to make a solution to store the Revo nozzles on my VT since i joined the pre-order, but hav been putting it off until "So I says..." posted he's take mod in discord.
When i saw his mod I finally got some creative juices flowing and jumped on it. I've allready come across a nice design on Printables for the nozzle retention part that I  had planned on
using allready, so I got to work putting this together into something usefull. And well, this is how it ended up. The 350mm variant can store 7 Revo nozzles (only 350mm avalible at the time of writing this).

###### Pictures:

###### To-do List
-Add a "stopper" for the nozzle holder so that it stops in the middle of the opening.
-Improve on some tolerances.
-Add support for 300mm & 250mm printers.

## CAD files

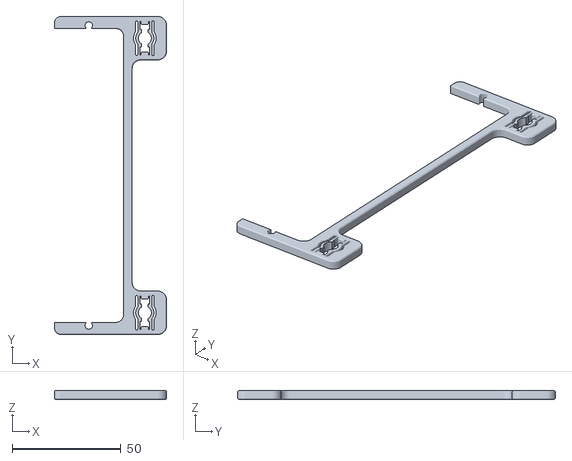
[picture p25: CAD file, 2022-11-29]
Mods/quick_release_exhaust_mount/STL/[a]_Exhaust_assembly_mount.stl
51.6 x 146.4 x 4.00

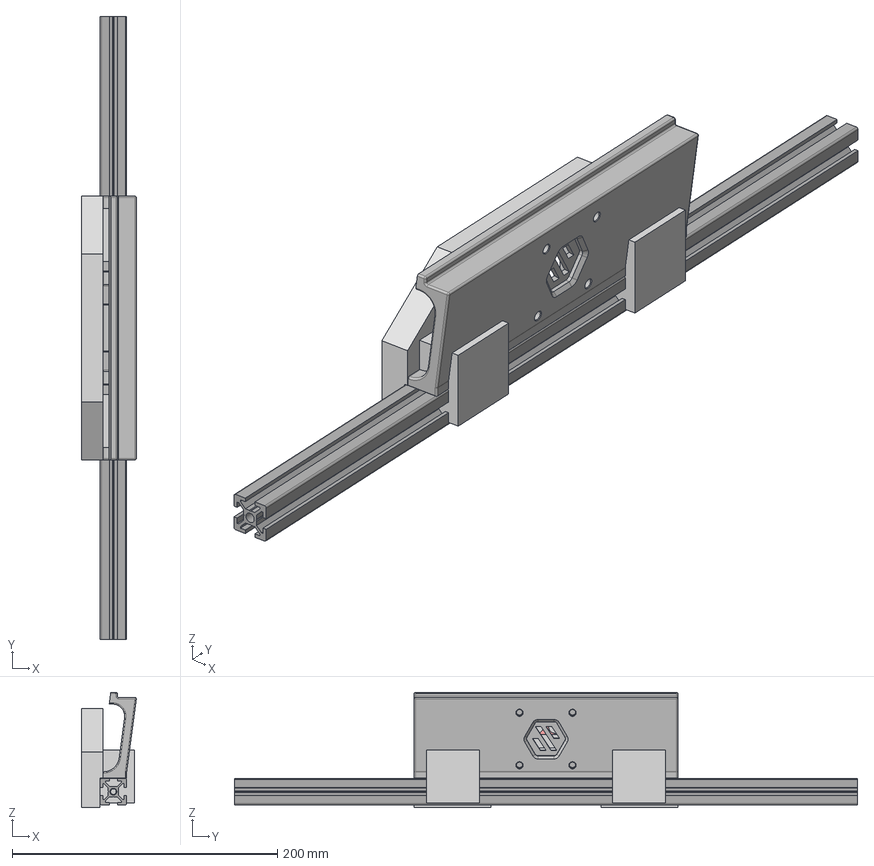
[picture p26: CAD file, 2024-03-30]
Mods/350mm_canopy_side_handles/CAD/350mm_Canopy_side_handles.step
41.3 x 470.0 x 87.1 mm
Canopy side
Handle
91292A123_18-8 Stainless Steel Socket Head Screw x 4
92095A212_NO THREADS x 2

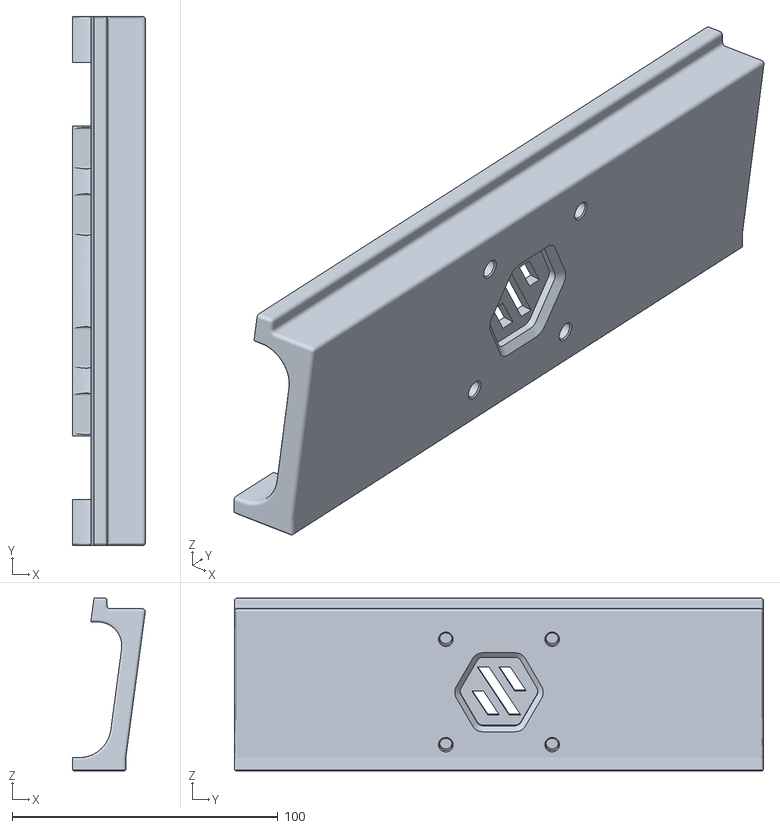
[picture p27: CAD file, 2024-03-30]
Mods/350mm_canopy_side_handles/STL/350 center.stl
27.3 x 199.0 x 65.0

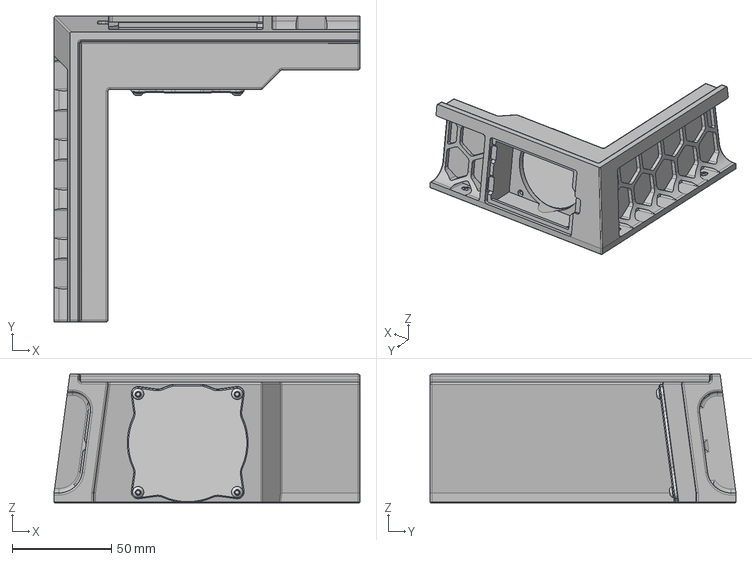
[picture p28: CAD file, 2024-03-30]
Mods/canopy_fan_blockoff/CAD/Exhaust_block_off_plate.step
154.5 x 154.5 x 65.0 mm
92095A179_NO THREADS x 4

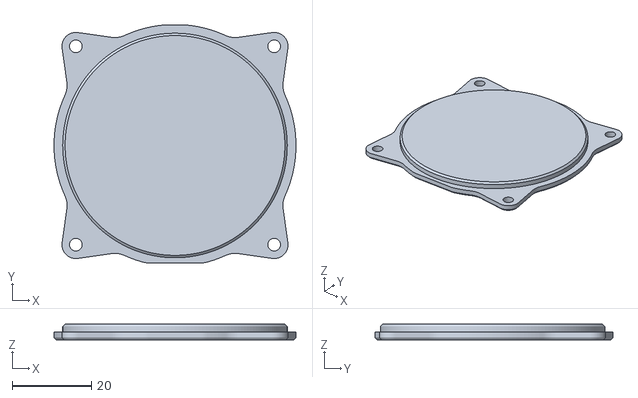
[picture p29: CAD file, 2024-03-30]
Mods/canopy_fan_blockoff/STL/Blockoff.stl
61.0 x 60.0 x 4.00

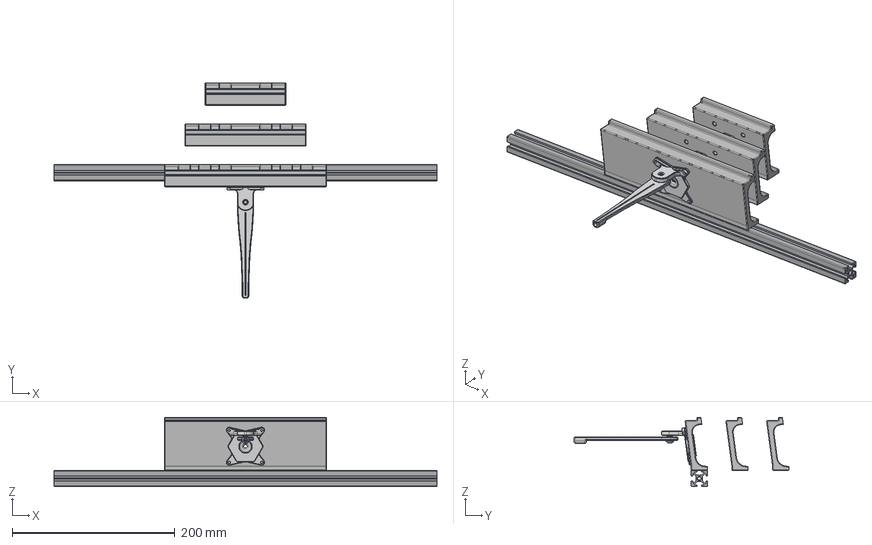
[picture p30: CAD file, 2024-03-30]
Mods/canopy_ptfe_passthrough/CAD/PTFE_passthrough.step
470.0 x 263.7 x 85.0 mm
PTFE passthrough_1
MR85 Bearing
M3x10 BHCS
Spacer
Arm mount

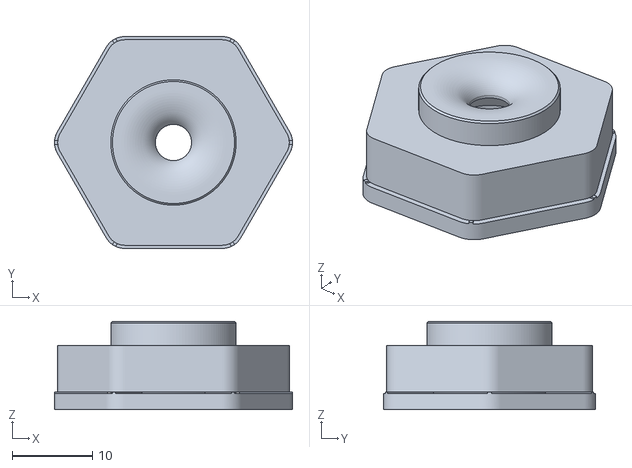
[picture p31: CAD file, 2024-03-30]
Mods/canopy_ptfe_passthrough/STL/[a]_PTFE_passthrough.stl
29.6 x 26.4 x 11.0

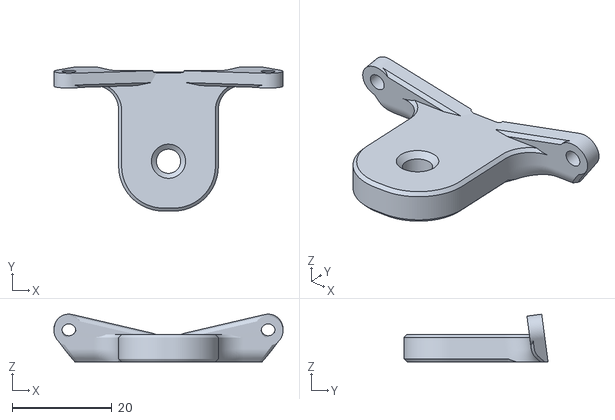
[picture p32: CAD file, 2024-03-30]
Mods/canopy_ptfe_passthrough/STL/ptfe-tube_support/Mount.stl
46.0 x 28.9 x 9.58

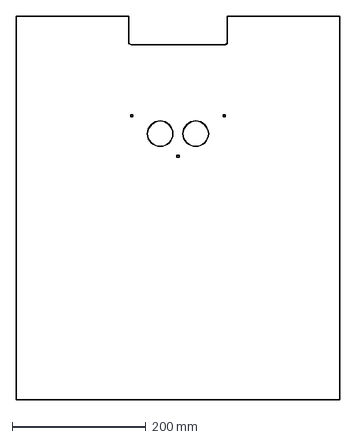
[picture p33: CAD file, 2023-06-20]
Mods/fume_pack/DXF/350x350mm.dxf
483.0 x 573.0 mm

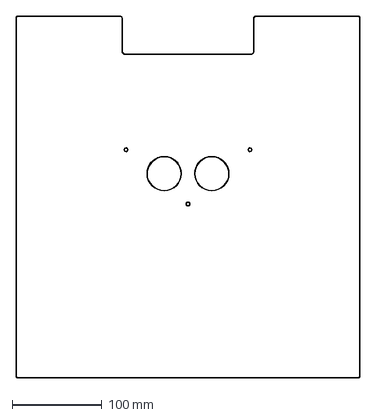
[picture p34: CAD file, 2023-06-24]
Mods/fume_pack/DXFs/V2-250mm.dxf
383.0 x 403.0 mm

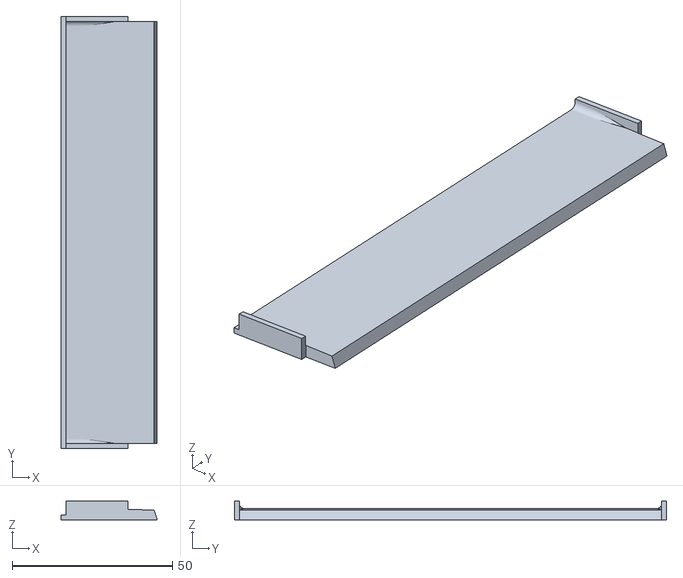
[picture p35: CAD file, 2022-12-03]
Mods/fume_pack/STL/Cover_plate_A-v1.2.stl
30.1 x 134.8 x 5.90

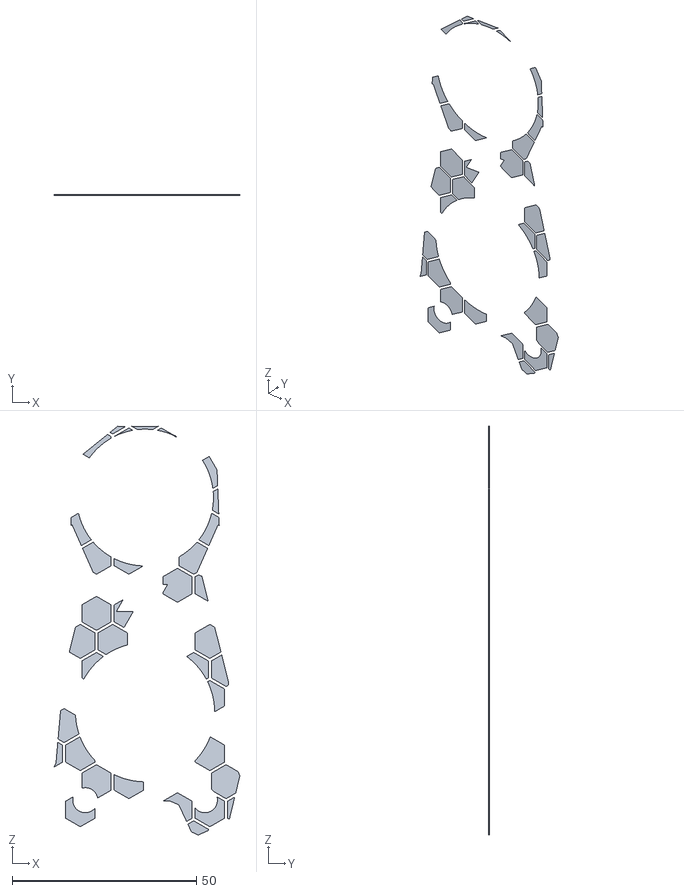
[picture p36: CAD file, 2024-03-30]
Mods/halo_hex/STL/2_colors/HALO-HEX_2_colors.stl
50.5 x 0.2 x 111.1

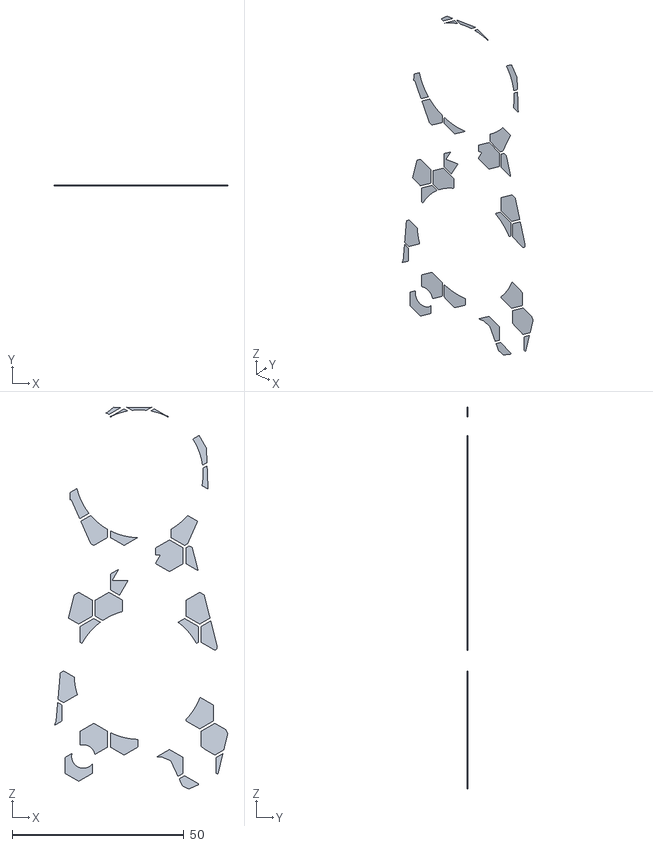
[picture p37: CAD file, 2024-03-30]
Mods/halo_hex/STL/3_colors/HALO-HEX_3_colors-1.stl
50.5 x 0.2 x 111.1

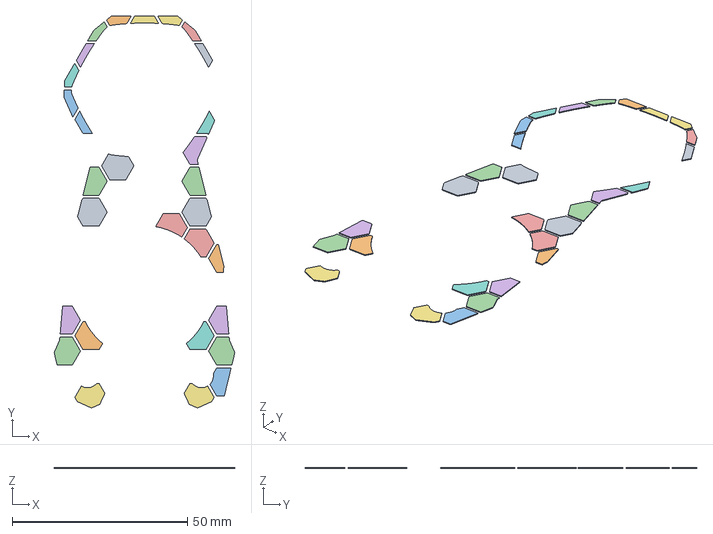
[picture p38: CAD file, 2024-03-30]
Mods/knomi_hex/CAD/KNOMI-Hex.step
51.5 x 111.7 x 0.2 mm

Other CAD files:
Mods/knomi_hex/midlertidig!/NO-KNOMI-h.stl
Mods/knomi_hex/STL/2_colors/KNOMI-HEX_2_colors.stl
Mods/knomi_hex/STL/3_colors/KNOMI-HEX_hex-2.stl
Mods/lgx-lite_filament_sensor/CAD/LGX-lite_filament_sensor.step
Mods/canopy_ptfe_passthrough/STL/250.stl
Mods/canopy_ptfe_passthrough/STL/300.stl
Mods/canopy_ptfe_passthrough/STL/350.stl
Mods/canopy_ptfe_passthrough/STL/Cover_plate.stl
Mods/canopy_ptfe_passthrough/STL/ptfe-tube_support/[a]_Spacer.stl
Mods/fume_pack/DXF/250mm.dxf
Mods/fume_pack/DXF/300mm.dxf
Mods/fume_pack/DXF/350mm.dxf
Mods/fume_pack/DXFs/V2-300mm.dxf
Mods/fume_pack/DXFs/V2-350mm.dxf
Mods/fume_pack/DXFs/VT-250mm.dxf
Mods/fume_pack/DXFs/VT-300mm.dxf
Mods/fume_pack/DXFs/VT-350mm.dxf
Mods/fume_pack/DXFs/VT-350x350mm.dxf
Mods/fume_pack/STL/Drill_template-v1.1.stl
Mods/fume_pack/STL/[TPU]_Right_gasket_x2-v1.1.stl
Mods/fume_pack/STL/[a]_Fan_cover-v1.1.stl
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

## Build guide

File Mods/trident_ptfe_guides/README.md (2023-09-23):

# Trident PTFE Guides
## CHANGELOG
- 23.09.2023: Added another set with 40mm radius as supposed to the first release that was 50mm. The two types are named `R40` & `R50` respectively.
- 01.12.2022: Initial release.

###### Printing:
- Default voron settings, correct orientation, no supports needed!

###### Bom:
- Only printed parts.

###### Description:
- Made to guide the PTFE tube uniformly into the extruder, and avoid rubbing against the top panel.
- One 90° version and one 105° version.
- The idea with the 105° is to point the PTFE tube slightly downwards so that it don't collide with the top side extrusions as badly, and / or bind up in them.

Note that this is intended to be used with an LGX Lite extruder, so i can't say if it will clear the top panel on a printer running a regular LGX, CW1 or CW2!

###### Pictures:
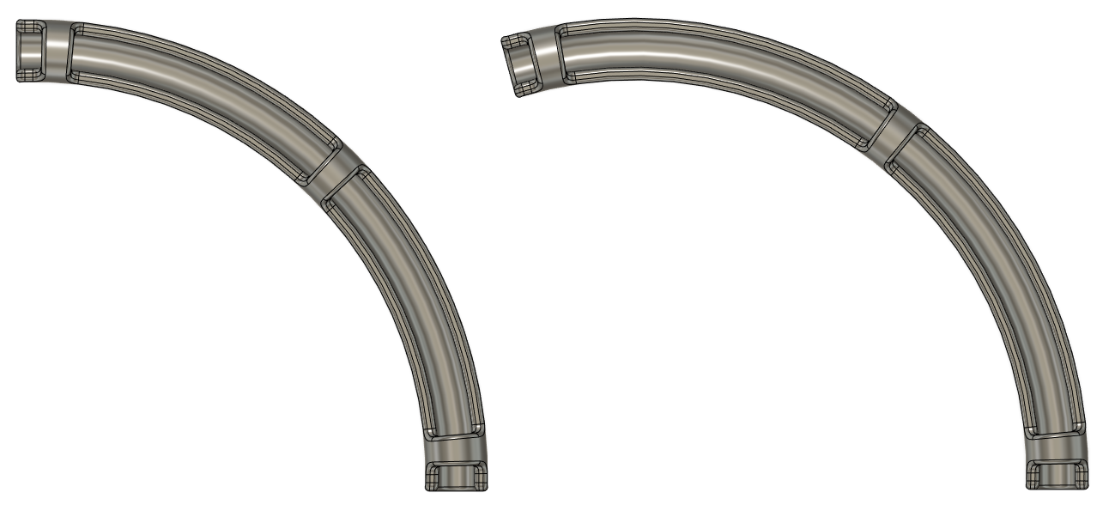
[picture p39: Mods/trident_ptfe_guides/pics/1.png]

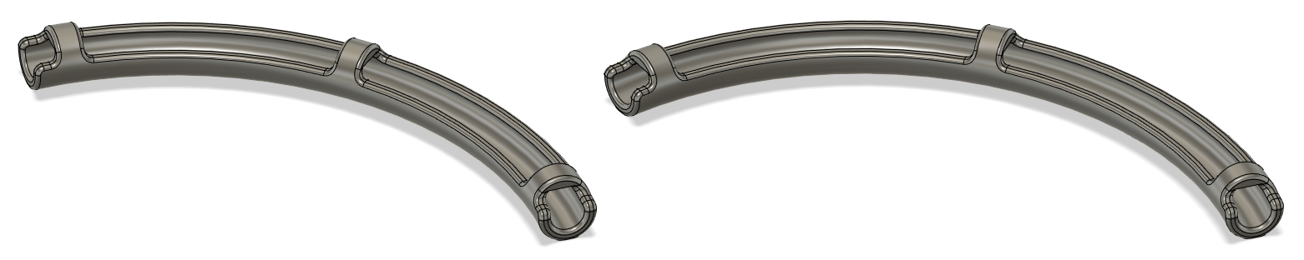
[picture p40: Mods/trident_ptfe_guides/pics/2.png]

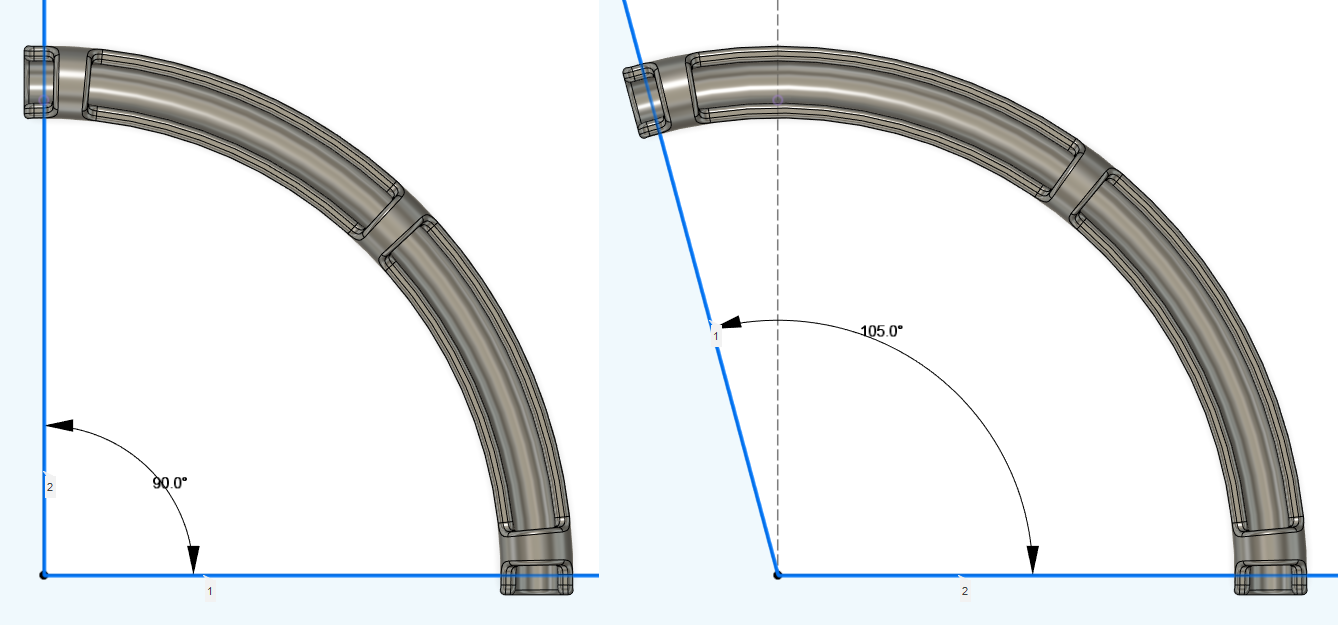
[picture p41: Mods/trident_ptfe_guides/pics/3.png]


###### To-do List
- Nothing that i can think of.

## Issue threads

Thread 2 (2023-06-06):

Sb_leds.g

TechsavvyCNC, 2023-06-06:
When trying to use you led code on rrf 3.5 beta 3.  I keep getting a error for sb_led-state.g.  it say variable sb_led.g not found or no variable.

Exerqtor, 2023-06-07:
Hmm maybe i forgot to push some changes 😬, I had to rework the macros a little due to changes in how neopixels are handeled from RRF 3.5b3 onwards.

I atleast have a working version running on my machine (Duet 3 Mini / RRF 3.5b3++), so it's probably just a derp on my end!

What board are you using btw?

TechsavvyCNC, 2023-06-07:
Duet 3 6hc

TechsavvyCNC, 2023-06-07:
Alright I'll give it a shot.  Do you have to copy the sb_leds-state and sb_leds-restore into sys/lib/led?

TechsavvyCNC, 2023-06-07:
I keep getting this error

Error: in file sb_leds-state.g line 8: unknown variable 'sb_leds'

Exerqtor, 2023-06-07:
Ehm ok? Have you decleared the the `global.sb_leds` variable?

TechsavvyCNC, 2023-06-07:
if var.sb_leds = global.sb_leds
  ; Same status, do nothing
else
  ; New status, change colors
  M98 P"/sys/lib/led/sb_leds.g"

Exerqtor, 2023-06-07:
Type `global sb_leds = "ready" ` in console.

TechsavvyCNC, 2023-06-07:
if i type global sb_leds = "ready" in the console then the error message goes away and the leds turn white.  When i home the printer they turn green like 8 seconds after its homed.  I added global sb_leds = "boot" and now it works after restarting the printer its just slow to change colors.

Exerqtor, 2023-06-08:
Ok glad to hear you got it working (even though it's slow).

I haven't had time/prioritized to write a better guide in regards to declaring `global.sb_leds` in the readme so that's on me. I'll try to update it soon™!

Regarding the colors changing slowly, have you got a delay set in your `daemon.g` or any of your homing macro's ? Thats the only reason I can think of that might make it slow.

Closed 2023-06-07.

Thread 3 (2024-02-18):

Rear Top support on Trident 250

phildabill, 2024-02-18:
Built a Formbot Trident 250 and noticed the rear center braces block the rear top supports.

Picture doesn't show it really well but the part was curving enough to make me uncomfortable to use it as-is.

I'm no 3d expert, but I mickey moused the step file to fit my purpose.

Also faced the issue that the cartographer probe was hitting the part so I removed part of it.

Thanks
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

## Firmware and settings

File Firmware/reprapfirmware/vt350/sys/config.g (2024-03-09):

; Configuration file for Duet 3 Mini 5+ with Duet 3 Expansion Mini 2+ and 1LC (firmware version 3.5)
; executed by the firmware on start-up

; For E3D Revo Micro, Bondtech LGX Lite & Voron TAP  --------------------------

; ====================---------------------------------------------------------
; Basic setup
; ====================

; General preferences
M575 P1 S1 B57600                                                              ; Enable support for PanelDue
M80 C"pson"                                                                    ; Allocates the pin and sets the pin in the power on state
M80                                                                            ; Sets pin in the power on state
;M81                                                                            ; Turn power off immediately

; Debugging
M111 S0                                                                        ; Debugging off (S0) or on (S1)

G21                                                                            ; Work in millimetres
G90                                                                            ; Send absolute coordinates...
M83                                                                            ; Set extruder to relative mode
M550 P"Voron Trident"                                                          ; Set printer name
G4 S2                                                                          ; Wait a moment for the CAN expansion boards to start

; Kinematics
M669 K1 X-1:-1:0 Y1:-1:0 Z0:0:1                                                ; Select CoreXY mode and set kinematics matrix

; Network
M552 S1                                                                        ; Enable network
G4 S1                                                                          ; Wait a second
M586 P0 S1                                                                     ; Enable HTTP (for DWC)
M586 P1 S1                                                                     ; Enable FTP (for remote backups etc.) S0 / S1 = disabled / enabled
M586 P2 S0                                                                     ; Disable Telnet

; ====================---------------------------------------------------------
; Driver config
; ====================

;          --- Drive map ---
; (While looking at the printer top down)

;             0.0-----0.1
;              |  0.2  |
;              |-------|
;              |0.3|0.4|
;               ---+---
;                Front

; Drives for XY
M569 P0.0 S0                                                                   ; X (B) (physical drive 0.0) goes backwards
M569 P0.1 S0                                                                   ; Y (A) (physical drive 0.1) goes backwards

; Drives for Z
M569 P0.2 S0                                                                   ; Z1 (physical drive 0.2) goes backwards
M569 P0.3 S0                                                                   ; Z2 (physical drive 0.3) goes backwards
M569 P0.4 S0                                                                   ; Z3 (physical drive 0.4) goes backwards

; Drive for extruder
M569 P121.0 S0                                                                 ; E (physical drive 121.0) goes backwards

; Motor mapping and steps per mm
M584 X0.0 Y0.1 Z0.2:0.3:0.4 E121.0                                             ; Set drive mapping
M350 X16 Y16 Z16:16 E16 I1                                                     ; Configure microstepping with interpolation
M92 X80.00 Y80.00 Z800.00                                                      ; Set XYZ steps per mm (1.8deg motors)
M92 E568.83                                                                    ; Set Extruder steps per mm (Bondtech LGX Lite 562 stock)

; Drive currents
M906 X1750 Y1750 I40                                                           ; Set XY motor currents (mA) and ide current percentage
M906 Z850 I40                                                                  ; Set Z motor currents (mA) and ide current percentage
M906 E650 I40                                                                  ; Set E motor currents (mA) and ide current percentage
M84 X Y Z E0 S30                                                               ; Set idle timeout

; ====================---------------------------------------------------------
; Motion config
; ====================

; Axis max jerk & speed limits in mm/s
var Xjrk = 12           ; X axis jerk
var Yjrk = 12           ; Y axis jerk
var Zjrk = 0.5          ; Z axis jerk
var Xspd = 500          ; X axis max speed
var Yspd = 500          ; Y axis max speed
var Zspd = 15           ; Z axis max speed

; Axis accelerations and speeds
M566 X{var.Xjrk * 60} Y{var.Yjrk * 60} Z{var.Zjrk * 60} P1                     ; Set maximum instantaneous speed changes (mm/min) and jerk policy
M203 X{var.Xspd * 60} Y{var.Yspd * 60} Z{var.Zspd * 60}                        ; Set maximum speeds (mm/min)
M201 X7000.00 Y7000.00 Z500.00                                                 ; Set accelerations (mm/s²) Z var 150

; Extruder max jerk & speed limits in mm/s
var Ejrk = 134          ; Extruder jerk
var Espd = 250          ; Extruder max speed

; Extruder accelerations and speeds
M566 E{var.Ejrk * 60} P1                                                       ; Set maximum instantaneous speed changes (mm/min) and jerk policy
M203 E{var.Espd * 60}                                                          ; Set maximum speeds (mm/min)
M201 E3000.0                                                                   ; Set accelerations (mm/s²) var 1800

; Reduced accelerations
M201.1 X500 Y500 Z80 E500                                                      ; Set reduced acceleration for special move types (mm/s²)

; Printing and travel accelerations
M204 P5000 T7000                                                               ; Set printing acceleration and travel accelerations (mm/s²)

; ====================---------------------------------------------------------
; Movement
; ====================

; Axis Limits
M208 X-1 Y-10 Z0 S1                                                            ; Set axis minimal
M208 X352 Y350 Z330 S0                                                         ; Set axis maximal

; Endstops
M574 Z0 P"nil"                                                                 ; No endstop

; Z-probe (Voron TAP)
M558 K0 P8 C"^121.io2.in" H2 R0.2 F300:180 T18000 A1 S0.03                     ; Set Z probe number ,type, input pin, dive height,recovery time, feed rate, travel speed, max probes & tolerance when probing multiple times
G31 K0 P500 X0 Y0 Z-1.170                                                      ; Set Z probe trigger value, offset and trigger height (higher Z value = nozzle closer to bed)

; Bed leveling

;        --- Pivot point map ---
; (While looking at the printer top down)
;               -------
;              |   1   |
;              |-------|
;              | 3 | 2 |
;               ---+---
;                Front

M671 X175:362:-49 Y390:12:12 S10                                               ; Leadscrew locations (Rear, Right, Left) M671 X175:388:-38 Y416.6:1.5:1.5 S10 
M557 X10:340 Y10:340 P12                                                       ; Define default mesh grid ( positions include the Z offset!)

; Accelerometer & Input shaping
M955 P121.0 I05                                                                ; Configure accelerometer
;M593 P"zvdd" F39.75 S0.0                                                       ; Use ZVDD input shaping to cancel ringing at 39.75Hz with 0.0 damping factor
M593 P"zvd" F41.5 S0.0                                                         ; Use ZVD input shaping to cancel ringing at 41.5Hz with 0.0 damping factor

; ====================---------------------------------------------------------
;  Heaters
; ====================

; Bed heater
M308 S0 P"temp0" Y"thermistor" T100000 B3950 A"Bed"                            ; Configure sensor 0 as thermistor on pin temp0
M950 H0 C"out0" T0 Q5                                                          ; Create bed heater output on out0, map it to sensor 0 and set PWM frequency(Hz)
M307 H0 B0 S1.00                                                               ; Disable bang-bang mode for the bed heater and set PWM limit
M140 H0                                                                        ; Map heated bed to heater 0
M143 H0 S110                                                                   ; Set temperature limit for heater 0 to 110°C
M143 H0 A2 C0 S110                                                             ; Make sure bed heater stays below 110°C
M143 H0 A1 C0 S125                                                             ; Make sure bed heater shuts down at 125°C
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

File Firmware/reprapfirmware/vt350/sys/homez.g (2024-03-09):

; /sys/homez.g  v2.9
; Called to home the Z axis

;---/
; -/--/--/--/--/--/--/--/--/--/--/--/--/--/--/--/--
; THIS MACRO ONLY WORKS WITH RRF 3.5.0b1 AND LATER!!
;--/--/--/--/--/--/--/--/--/--/--/--/--/--/--/--/--
;-/

; ====================---------------------------------------------------------
; Settings section
; ====================

; Nozzle clearance (gets overridden if you have global.Nozzle_CL)
var Clearance = 5                                                              ; The "safe" clearance you want to have between the noszzle and bed before moving the printhead

; Probe number
var Probe = 0                                                                  ; The probe you want to use to home the Z axis

; Don't touch anyting bellow this point(unless you know what you're doing)!!
; ====================---------------------------------------------------------
; Prep phase
; ====================

; Nozzle clearance
if exists(global.Nozzle_CL)
  set var.Clearance = {global.Nozzle_CL}

; LED status
if exists(global.sb_leds)
  set global.sb_leds = "homing"

; ====================---------------------------------------------------------
; Lower Z axis
; ====================
if exists(param.Z)                                                             ; param.Z passed means that Z clearance is already dealt with
  ; No need to do anything, the nozzle is already been cleared
  
elif
  if !move.axes[2].homed                                                       ; If Z isn't homed
    ; Lower Z currents
    if fileexists("/sys/lib/current/z_current_low.g")
      M98 P"/sys/lib/current/z_current_low.g"                                  ; Set low Z currents
    else
      M913 Z60                                                                 ; Set Z motors to n% of their max current

    G91                                                                        ; Relative positioning
    G1 Z{var.Clearance} F9000 H1                                               ; Lower Z(bed) relative to current position
    G90                                                                        ; Absolute positioning

    ; Full Z currents
    if fileexists("/sys/lib/current/z_current_high.g")
      M98 P"/sys/lib/current/z_current_high.g"                                 ; Set high Z currents
    else
      M913 Z100                                                                ; Set Z motors to 100% of their max current

  elif move.axes[2].userPosition < {var.Clearance}                             ; If Z is homed but less than var.Clearance
    ; Lower Z currents
    if fileexists("/sys/lib/current/z_current_low.g")
      M98 P"/sys/lib/current/z_current_low.g"                                  ; Set low Z currents
    else
      M913 Z60                                                                 ; Set Z motors to n% of their max current

    G1 Z{var.Clearance} F9000                                                  ; Move to Z var.Clearance

    ; Full Z currents
    if fileexists("/sys/lib/current/z_current_high.g")
      M98 P"/sys/lib/current/z_current_high.g"                                 ; Set high Z currents
    else
      M913 Z100                                                                ; Set Z motors to 100% of their max current

; ====================---------------------------------------------------------
; Home Z axis
; ====================
if exists(param.A)                                                             ; param.A passed means that this is the first part of a homing sequence, so we don't want to lower the currents
  ; No need to do anything, at this point

elif
  if exists(param.C)                                                           ; param.C passed means that the currents are handeled externaly 
    ; No need to do anything, currents have been adjusted already  

  elif
    ; Lower Z currents
    if fileexists("/sys/lib/current/z_current_low.g")
      M98 P"/sys/lib/current/z_current_low.g"                                  ; Set low Z currents
    else
      M913 Z60                                                                 ; Set Z motors to n% of their max current

var maxP = sensors.probes[{var.Probe}].maxProbeCount
M558 K{var.Probe} A2                                                           ; Increase to 2 max probes

; Move to bed center and home Z
M98 P"/sys/lib/goto/bed_center.g"                                              ; Move to bed center
G30 K{var.Probe} Z-99999                                                       ; Probe the center of the bed
M400                                                                           ; Wait for moves to finish

M558 K{var.Probe} A{var.maxP}                                                  ; Restore default max probe amount

; ====================---------------------------------------------------------
; Finish up
; ====================
; Uncomment the following lines to lower Z(bed) after probing
G90                                                                            ; Absolute positioning
G1 Z{var.Clearance} F2400                                                      ; Move to Z var.Clearance

; If using Voron TAP, report that probing is completed
if exists(global.TAPPING)
  set global.TAPPING = false
  M402 P0       
if exists(param.A)                                                             ; param.A passed means that this is the first part of a homing sequence, so we don't want to raise the currents
  ; No need to do anything, at this point

elif
  if exists(param.C)                                                           ; param.C passed means that the currents are handeled externaly 
    ; No need to do anything, currents have been adjusted already

  elif
    ; Full XY currents
    if fileexists("/sys/lib/current/xy_current_high.g")
      M98 P"/sys/lib/current/xy_current_high.g"                                ; Set high XY currents
    else
      M913 X100 Y100                                                           ; Set X Y motors to var.100% of their max current
    if fileexists("/sys/lib/current/z_current_high.g")
      M98 P"/sys/lib/current/z_current_high.g"                                   ; Set high Z currents
    else
      M913 Z100                                                                  ; Set Z motors to var.100% of their max current

                                                               ; Return the hotend to the temperature it had before probing

  ;LED status
  if exists(global.sb_leds)
    set global.sb_leds = "ready"

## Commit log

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2022-07-16 Initial release
    [7_nozzle_holder.stl, MM_[a]_logo_side_skirt_b_350mm.stl, MM_lid_side_skirt_b_350mm.stl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]
2022-07-16 multi_material
    Added multi_material folder and moved the MM parts accordingly.
    [MM_[a]_logo_side_skirt_b_350mm.stl, MM_lid_side_skirt_b_350mm.stl]
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2022-07-31 Update daemon.g
    v1.1
    [daemon.g]
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2022-08-07 Fixed print orientation
    [Drill_template-v2.1.stl]
2022-11-28 Changed to v2
    [Drill_template-v2.1.stl]
2022-11-28 Update to v2.2
    [Drill_template-v2.1.stl, Drill_template-v2.2.stl, [TPU]Fan_gasket_x2-v2.2.stl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]
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2022-11-30 Added rail stop
    [MGN12H_Z_Carriage_Rear.step, [a]_z_rail_stop-MGN12.stl]
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2022-12-01 Naming correction
    [[TPU]_Fan_gasket_x2-v2.2.stl, [a]_Cartridge_lid-v2.2.stl, [a]_Fan_cover-v2.2.stl]
2022-12-02 Moved VT wire holes
    Moved the wire routing holes that exit right bellow the rear gantry extrusion (VT) down a little bit.
    [Drill_template-v2.2.stl]
2022-12-02 Moved VT wiring holes
    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
    [Drill_template-v1.1.stl]
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2022-12-19 v2.1
    Minor script cleanup
    [deployprobe0.g]
2022-12-21 Update config.g
    Removed debugging global crap
    [config.g]
2022-12-21 Global renaming
    Changed the names on some globals.
    Old / new:
    - TAP_Clearance / Nozzle_CL
    - probing / TAPPING
    [bed.g, deployprobe0.g, homeall.g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]
2022-12-21 Update homeall.g
    Removed useless code
    [homeall.g]
2022-12-21 Update mesh.g
    Typoes
    [mesh.g]
2022-12-21 Typo correction
    Forgot to put bracets around globals in some `if exists` conditions
    [M48.g, bed.g, homeall.g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]
2022-12-23 Code fix
    Had forgot to invoke `G91 Relative positioning` to lower bed if Z wasn't homed.
    [M48.g, bed.g, homeall.g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]
2022-12-24 Update config.g
    Separate idle current settings for XY,Z & E. With higher reduction than before.
    [config.g]
2022-12-24 Update config.g
    Drive map update
    [config.g]
2022-12-24 Update M48.g
    Changed wording
    [M48.g]
2022-12-24 Added variable
    Added variable for drive numbers
    [homeall.g, homex.g, homey.g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]
2022-12-31 Takedown
    Not stable, removed TEMPORARY!
    [homeall.g, homex.g, homey.g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]
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2023-01-02 Speed & accel removal
    Removed manual speed & acceleration controll for printing(normal conditions) and probing in favour of using M201.1 & M204 in config.g.
    The changes apply to many macros, you will get an error each time you try to execute a file/macro that looks for the speed related macros. Update them as they come!
    [bed.g, config.g, homeall.g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]
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2023-01-04 global.job_completion removal
    Obsolete global removed.
    [cancel.g]
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2023-01-05 stop.g
    RRF 3.5 preparation where stop.g gets ran at the end of all completed prints.
    [stop.g]
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2023-01-06 Tramming
    In the spirit of using the right maching terms, "leveling" has been switched out for "tramming" (whitch is what's actually being done).
    [bed.g]
2023-01-08 V3.0
    Adapted the macro for RRF 3.5
    [M48.g]
2023-01-08 V3.0
    https://github.com/Exerqtor/Voron/commit/98cbb678e7306cec8c207b100ce1d9b67476d186
    [M48.g]
2023-04-11 WobbleX
    v1
    [WobbleX-MGN12H_Z_Carriage_Rear.step, WobbleX-MGN12H_Z_Carriage_Rear_2-hole-(IGUS).stl, WobbleX-MGN12H_Z_Carriage_Rear_3-hole-(Generic).stl]
2023-04-11 Counterbore fix & WobleX v1.5
    Fixed the overhangs on the counterbore holes so they match up with VTr1.
    - - -
    WobbleX v1.5 has the same counterbore fixes & the MGN12H block has been moved 2mm farther down.
    [MGN12H_Z_Carriage_Rear.step, MGN12H_Z_Carriage_Rear_2-hole-(IGUS).stl, MGN12H_Z_Carriage_Rear_3-hole-(Generic).stl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]
2023-04-13 V2 350mm
    [[a]_front_skirt_a_350-mesh.stl, [a]_front_skirt_b_350-mesh.stl, [a]_side_skirt_a_350-mesh_x2.stl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]
2023-04-13 V2 300mm
    [[a]_front_skirt_a_300-mesh.stl, [a]_front_skirt_b_300-mesh.stl, [a]_side_skirt_a_300-mesh_x2.stl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]
2023-04-13 V2 250mm
    [[a]_front_skirt_a_250-mesh.stl, [a]_front_skirt_b_250-mesh.stl, [a]_side_skirt_a_250-mesh_x2.stl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]
2023-04-13 V2 CAD
    [V2_Mesh_skirts.step]
2023-04-14 WobbleX v1.6
    Added recess for the WobbleX balls (missing in stock/MGN9H release too).
    [WobbleX-MGN12H_Z_Carriage_Rear.step, WobbleX-MGN12H_Z_Carriage_Rear_2-hole-(IGUS).stl, WobbleX-MGN12H_Z_Carriage_Rear_3-hole-(Generic).stl]
2023-04-14 WobbleX v1.7
    Resized the pin holes too 2.9mm (the old/stock was 3.1mm and the pins would be loose and fall out).
    [WobbleX-MGN12H_Z_Carriage_Rear.step, WobbleX-MGN12H_Z_Carriage_Rear_2-hole-(IGUS).stl, WobbleX-MGN12H_Z_Carriage_Rear_3-hole-(Generic).stl]
2023-04-20 v1.6
    Changed wording of M291 message, and the purge is done BEFORE moving the nozzle close to the bed again.
    [filament-change.g]
2023-04-20 MM lid fix
    [MM-revo_nozzle_lid_1_350_FL.stl, MM-revo_nozzle_lid_350_FL.stl, MM-revo_nozzle_lid_3_350_FL.stl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]
2023-04-21 Accent naming
    Had forgot to add [a] at the front of the parts meant to be printed in accent colors.
    [[a]_front_skirt_a_250-mesh.stl, [a]_front_skirt_a_300-mesh.stl, [a]_front_skirt_a_350-mesh.stl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]
2023-04-22 Adams tech inlet
    I had forgot to add the STL & CAD for the Adams tech inlet, now been added.
    [[a]_power_inlet_adamstech.stl, power_inlet_adamstech.stl]
2023-04-22 Feature fix
    I found a fault in the official CAD & .stl. Fixed in this update, refere to the issue I made: https://github.com/VoronDesign/Voron-Trident/issues/117
    [power_inlet_filtered.stl]
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2023-04-23 Print orientation correction
    [WobbleX_z_carriage_left.stl]
2023-04-25 WobbleX test model
    Made a test model to determine what size you need choose to run depending in how your tolerances are.
    [WobbleX_pin_test.stl]
2023-04-25 Chamfer adjustment
    [Pin clearance test.step, WobbleX_pin_test.stl]
2023-04-25 Print orientation fix
    [WobbleX_z_carriage_left.stl, WobbleX_z_carriage_right.stl]
2023-04-25 Variable pin sizes
    [WobbleX-MGN12H_Z_Carriage_Rear.step, WobbleX-MGN12H_Z_Carriage_Rear_2-hole-(IGUS).stl, WobbleX-MGN12H_Z_Carriage_Rear_3-hole-(Generic).stl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]
2023-04-25 WobbleX TR8 Adapters
    [WobbleX_2.9mm_TR8_Adapter.stl, WobbleX_3.0mm_TR8_Adapter.stl, WobbleX_3.1mm_TR8_Adapter.stl]
2023-04-26 Export fix
    [WobbleX_2.9mm_z_carriage_left.stl, WobbleX_2.9mm_z_carriage_right.stl, WobbleX_3.0mm_z_carriage_left.stl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]
2023-04-26 Update Pin clearance test.step
    [Pin clearance test.step]
2023-04-26 Chamfer fix
    Removed a little part of the chamfers at the opening of the pinholes.
    [WobbleX-MGN12H_Z_Carriage_Rear.step, WobbleX_2.9mm-MGN12H_Z_Carriage_Rear_2-hole-(IGUS).stl, WobbleX_2.9mm-MGN12H_Z_Carriage_Rear_3-hole-(Generic).stl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]
2023-04-26 Print orientation fix, AGAIN
    [WobbleX_2.9mm_z_carriage_left.stl, WobbleX_3.0mm_z_carriage_left.stl, WobbleX_3.1mm_z_carriage_left.stl]
2023-05-01 13mm hole
    [WobbleX_2.9mm-MGN9H_Z_Carriage_Rear_2-hole-(IGUS).stl, WobbleX_2.9mm-MGN9H_Z_Carriage_Rear_3-hole-(Generic).stl, WobbleX_2.9mm_TR8_Adapter.stl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]
2023-05-01 13mm hole WobbleX
    [WobbleX-MGN12H_Z_Carriage_Rear.step, WobbleX_2.9mm-MGN12H_Z_Carriage_Rear_2-hole-(IGUS).stl, WobbleX_2.9mm-MGN12H_Z_Carriage_Rear_3-hole-(Generic).stl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]
2023-05-08 SB Release version
    [LGX Lite SB ERCF OPEN.step, OPEN-front_body_lgx_lite_sb_erfc.stl, OPEN-rear_body_lgx_lite_sb_ercf.stl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]
2023-05-18 Fix
    Forgot to include the support when exporting to .stl
    [left.stl, right.stl]
2023-06-20 DXF files
    DXF files for cutting of the rear panel.
    [250mm.dxf, 300mm.dxf, 350mm.dxf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]
2023-06-20 3.5mm holes
    Changed the mounting holes from 4.7mm to 3.5mm
    [250mm.dxf, 300mm.dxf, 350mm.dxf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]
2023-06-24 4mm holes & V2
    [V2-250mm.dxf, V2-300mm.dxf, V2-350mm.dxf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]
2023-06-24 Folder name change DXF->DXFs
    [V2-250mm.dxf, V2-300mm.dxf, V2-350mm.dxf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]
2023-06-25 June 25th 2023 update.
    [MM-revo_nozzle_lid_350_FL.stl, MM-revo_nozzle_side_skirt_a_350-brim_ears.stl, MM-revo_nozzle_side_skirt_a_350-lid.stl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]
2023-08-06 Debossed Wobblex logo
    [WobbleX_2.9mm_z_carriage_left.stl, WobbleX_2.9mm_z_carriage_right.stl, WobbleX_3.0mm_z_carriage_left.stl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]
2023-08-06 Wobblex logo deboss
    [WobbleX_2.9mm-MGN9H_Z_Carriage_Rear_2-hole-(IGUS).stl, WobbleX_2.9mm-MGN9H_Z_Carriage_Rear_3-hole-(Generic).stl, WobbleX_3.0mm-MGN9H_Z_Carriage_Rear_2-hole-(IG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]
2023-08-07 Wobblex merge
    [Pin clearance test.step, Rear Wobblex Carriers-MGN12H.step, WobbleX_2.9mm-MGN12H_Z_Carriage_Rear_2-hole-(IGUS).stl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]
2023-08-07 Top support release
    [Top supports.step, bearing-leadscrew_adapter_x3.stl, front_left_top_support.stl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]
2023-09-23 R40
    Made a 40mm radius version as well, hence some name changes etc.
    [R40-105°.stl, R40-90°.stl, R50-105°.stl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]
2023-09-23 Update M48.g
    Updated to work with RRF 3.5.0rc1 and newer.
    [M48.g]
2024-03-09 Homing v2.9
    Updated homing files
    [homeall.g, homex.g, homey.g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]
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2024-03-09 cancel.g & stop.g update
    [cancel.g, stop.g]
2024-03-09 pause.g & resume.g update
    [pause.g, resume.g]
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2024-03-10 deployprobe0.g & retractprobe0.g update
    [deployprobe0.g, retractprobe0.g]
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2024-03-10 Updated bed.g & mesh.g
    [bed.g, mesh.g]
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2025-02-17 Printing orientation fix
    [LGX-lite_filament_sensor.stl, PTFE_cut_jig.stl]
